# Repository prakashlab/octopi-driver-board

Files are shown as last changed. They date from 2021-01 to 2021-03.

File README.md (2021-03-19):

# octopi-driver-board

Driver electronics for the Octopi and Squid microscope families.

3D render of the driver electronics stack

This repository contains the design files for printed circuit boards (PCBs) for driving the sensors and actuators of the Octopi and Squid families of microscopes.

## Background

### Motivation

[Octopi](https://www.biorxiv.org/content/10.1101/684423v1), short for _Open configurable high-throughput imaging platform for infectious disease diagnosis_, is a low-cost and reconfigurable autonomous microscopy platform capable of automated slide scanning and correlated bright-field and fluorescence imaging. It has been developed for malaria microscopy, and its modular design also provides a framework for new disease-specific modules to be developed.

Photo of the Octopi microscope

[Squid](https://squid-imaging.org/), short for _Simplifying quantitative imaging platform development and deployment_, is a toolkit for implementing research microscopes with advanced imaging capabilities comparable to what's available in commercial solutions, but at a fraction of the cost and with much higher portability. Squid provides a full suite of hardware and software components for rapidly configuring high-performance microscopes tailored to users' applications with reduced cost, effort, and turnaround time. Besides increasing accessibility of research microscopes and available microscope hours to labs, it is also designed to simplify development and dissemination of new or otherwise advanced microscopy techniques.

CAD renders of three configurations of the Squid microscope

Because the modules of the Octopi and Squid microscopes contain various sensors and actuators which need to be electronically driven and integrated into a complete system, the Squid project also provides printed circuit boards for interfacing and controlling these modules. This repository contains the designs for printed circuit boards needed to drive these microscopes.

### Design Overview

Subsystems of the driver electronics are organized as discrete modules which are integrated into the overall system by being stacked. These modules are PCBs which are electrically connected through board-to-board connectors and mechanically connected through standoffs at their corners, reminiscent of the [PC/104](https://en.wikipedia.org/wiki/PC/104) family of standards for embedded computer form factors and communication buses. The stacking system is called the _Octopi Driver Stack_ (ODS), while the boards which are stacked are called _planes_. There are also boards which are not part of the stack but rather connect to planes; because these are peripheral to the system, they are called _peripheral boards_. Planes and peripheral boards may also have smaller circuit boards mounted onto them, which are called _daughter boards_.

Each board is given a two-part name code, consisting of a name code for the type of board followed by a name code for the specific design of the board. Each board is associated with a version of the Octopi Driver Stack (which provides information about compatibility between planes) and an independent version of the board itself (which provides information about functionality within planes and connector interfaces between the plane and daughter boards or peripheral boards). Version numbers follow the [Sematic Versioning 2.0.0](https://semver.org/) specification.

ODSv1.0.0 consists of planes measuring 150 mm x 150 mm which are all connected to each other by shared data and power bus lines for all GPIO provided by a microcontroller. Each corner of a plane has a mounting hole sized for an M3 standoff; these mounting holes are spaced 140 mm apart, with 5 mm between the center of each hole and its two nearest edges. Each corner of the plane is a rounded corner of radius 5 mm. The four edges of each plane are allocated to different functionalities:

- The front edge contains indicator LEDs, as well as connectors and circuity for the shared data and power bus lines which connect all planes together in a stack. In this project, these connectors and circuitry are collectively called the _backbone_ of ODSv1.0.0; at the level of hardware these elements are just a bus like in the PC/104 architecture, but our project uses the term "backbone" so that we can use the word "bus" only to describe standard buses (e.g. SPI, I2C) which the "backbone" is organized around. Each plane has two connectors for the backbone system, and they are at the same position but on opposite faces of the PCB. On the bottom face, a Hirose [FunctionMAX FX20-120S-0.5SV](https://www.hirose.com/product/p/CL0570-1105-6-00) receptacle is used. On the top face, a Hirose FunctionMax [FX20-120P-0.5SV15](https://www.hirose.com/product/p/CL0570-1005-1-00) header or [FX20-120P-0.5SV20](https://www.hirose.com/product/p/CL0570-1011-4-00) header is used, depending on the height of components on the top face of the board. These connectors are positioned so that their centers are 55 mm from the left edge of the plane and 35 mm from the front edge of the plane. The connectors are oriented so that their long edges are parallel with the front and rear edges of the plane, and so that pin 1 is farthest from the left-front corner of the plane.
- The left edge contains input and output power connectors.
- The right edge contains analog and digital signal connectors.
- The rear edge contains rarely-used or rarely-accessed connectors.

ODSv1.0.0 consists of a single central processing plane (board type name code `PP`, short for _Processing Plane_), which is stacked together with other planes consisting mainly of SPI devices, such as for:

- Motion control (board type name code `MP`, short for _Motion Plane_)
- Camera synchronization (board type name code `CP`, short for _Camera Plane_)
- Illumination control (board type name code `IP`, short for _Illumination Plane_)
- Thermal control (board type name code `TP`, short for _Thermal Plane_)
- Sensing (board type name code `SP`, short for _Sensing Plane_)
- Fluids control (board type name code `FP`, short for _Fluids Plane_)
- I/O prototyping breakout (board type name code `BP`, short for _Breakout Plane_)

The SPI devices on these planes are addressed through [a hierarchical chip-select multiplexing scheme](https://ethanj.li/posts/2021/01/unyielding-foundations#iteration-3-more-modularity-becomes-necessary) to enable composition of planes for customization, reconfiguration, and expansion of capabilities.

Every plane is separated by a distance of either 15 mm or 20 mm from the plane above it, depending on the height of components on the top face of the plane. All tall components should only be on the top face of the plane.

## Install

To set up your computer for using this repository, you will need to install [KiCad](https://kicad.org/) version 5.1.9; note that this repository relies on KiCad footprints which exist in 5.1.9 and not in earlier versions. You should have the default symbol, footprint, and 3-D model libraries provided by KiCad. References to custom symbols, footprints, and 3-D models will work out-of-the-box, as they are all provided in this repository and referenced in KiCad relative to the `${KIPRJMOD}` environment variable.

To prepare 3D models for components, you will need to download [FreeCAD 0.19](https://github.com/FreeCAD/FreeCAD/releases/tag/0.19_pre) and install the [KiCad StepUp workbench](https://github.com/easyw/kicadStepUpMod).

## Usage

This repository is structured so that every board has its own top-level directory with the following naming scheme:

- Templates: `ODSv<Octopi Driver Stack version>-<template type name code>-<specific design name code, if any>`
- Planes: `ODSv<Octopi Driver Stack version>-<board type name code>-<specific design name code>`
- Peripheral boards and daughter boards: `<board type name code>-<specific design name code>`

Each directory has a short README describing the contents of the directory. All boards are designed in KiCad. Only the most recent version of each board is included at the HEAD of the repository; older versions of boards are tagged on Git and archived in this repository's Github Releases. You can review the design files without KiCad, by viewing [this project on CADLab.io](https://cadlab.io/project/23992).

Templates are provided as starters to copy for creating new boards. For more information, refer to [ODSv1.0.0-BT/README.md](ODSv1.0.0-BT/README.md).

All footprints, documentation, CAD models, and KiCad libraries for components and daughter boards used with the ODSv1.0.0 boards are available in the `Parts` directory.

Unit tests for the ODSv1.0.0 boards are available in the `Tests` directory. These are Arduino sketches intended to be uploaded to the Teensy for basic verification of board functionality.

A KiCad project which mechanically integrates all planes in the ODSv1.0.0 stack for 3D rendering is in the `ODSv1.0.0` directory.

### Extending Functionality

This repository will provide planes and boards which implement a core set of functionalities. When you need to prototype new functionalities integrated into the driver stack, you should the [ODSv1.0.0-BP-Jmp](ODSv1.0.0-BP-Jmp) breakout plane, which is designed to enable prototyping. To start out, just connect the components you need with jumper wires to the various header pins on that plane; whenever possible, you should prefer using the SPI bus and the pins in the GPIO section. If you run out of available GPIO pins, if you need to assemble many copies of your prototype, or if you need more breakouts, then you should integrate your components as a new plane and, ideally, submit your plane to this repository. To do so:

1. Wherever possible, shift your use of GPIO pins on BP-Jmp to the plane's SPI I/O expanders for digital I/O, ADC, and DAC. The headers for those components are in the middle of the plane.
2. Create a new plane as a copy of the [ODSv1.0.0-BT](ODSv1.0.0-BT) starter template. For more information, refer to [ODSv1.0.0-BT/README.md](ODSv1.0.0-BT/README.md).
3. Add the standardized SPI I/O expanders, which are used in the BP-Jmp plane, to meet your GPIO needs; and add other SPI devices as needed. You will need to add the standardized pull-up resistor on the CS pin of each SPI device. For devices whose DOUT/DO/MISO/CIPO pins are not tri-state, you will need to add the standardized tri-state buffer between the pin and the CIPO line, which should be controlled by the same demultiplexed DCS line as the SPI device's CS pin; this tri-state buffer also needs a standardized bypass capacitor.
4. Add I2C devices if no alternative with an SPI interface is available. You will need to add the standardized bus switch between the SDA/SCL pins of each device and the SDA/SCL bus, and you should control the bus switch using one of the demultiplexed DCS lines; you will need to add the standardized pull-up resistor onto this line. This bus switch also needs a standardized bypass capacitor.

Where appropriate, you should delegate functions in your plane onto daughter boards. For example, if there is a particularly complex or expensive subsystem which you need to be able to swap out or test independently, or if you are reusing the same subsystem multiple times, you may want to make daughter board PCBs - each with one copy of the subsystem - which you can plug in to your new plane.

### Releases

Snapshots of boards for fabrication/assembly are tagged and associated with releases. Each release comes with the following attachments:

- The schematic diagram (`*-schematic.pdf`)
- A drawing of the footprints and silkscreens on the top face of the board (`*-silk-top.pdf`)
- A 2-D rendering of the top face of the board, including copper and silkscreens (`*-board-*-top.png`)
- Gerber and drill files for fabricating the board with PCBway (`*-gerb.zip`)
- A complete archive of all diagrams, drawings, renderings, and fabrication and assembly files for the board (`*-docs-rev*.zip`)

### Automated Exports

The assets attached with releases are automatically generated from a Github Actions workflow in this repository. This workflow is automatically run for commits in all pull requests and for any pushed commit.

The workflow can also be manually triggered from the [KiCad Exports](https://github.com/prakashlab/octopi-driver-board/actions?query=workflow%3A%22KiCad+Exports%22) page, with the following parameters:

- Branch: Use this to specify which branch to use for the workflow.
- Git ref: Use this to specify which commit of the design files to export. If you leave it blank, it will do an export from the most recent commit on the selected branch. If you give it a tag name or commit SHA hash, the workflow will export files from the corresponding commit.
- Boards: Use this to specify which boards to export. If you leave it blank, it will export all boards. If you want to export multiple boards, separate their names with spaces (e.g. `ODSv1.0.0-PP-T41 ODSv1.0.0-CP-5x`).
- Variants: Use this to specify which variants of each board to export. If you leave it blank, it will export only the default variant of all specified boards. You should only use this field if you have specified exactly one board to export; otherwise, leave it blank. If you want to export multiple variants, separate them with spaces (e.g. `Default Pufferfish`).

## Maintainers

Currently the maintainer of this repository is [Ethan Li](https://github.com/ethanjli).

## Contributing

The ODSv1.0.0 system is still at an early stage, and we do not have capacity to provide extensive support to people interested in contributing to the project. We have not yet set up public infrastructure for users to ask questions. We will look at pull requests but we do not yet have a process for accepting them. However, we are excited to build a community of contributors, so as this repository matures we will work to set up these processes and systems.

All contributions should be made through pull-requests. Before a pull request is merged, every author or co-author of the pull request must add a comment answering the following questions:

1. This project is licensed under Apache License v2.0 for any software, and Solderpad Hardware License v2.1 for any hardware - do you agree that your contributions to this project will be under these licenses, too? **Indicate response here** (the contributions will only be accepted if all co-authors agree)
2. Were any of these contributions also part of work you did for an employer or a client? If so, do you have their permission to release it? **Indicate responses to both questions here** (the contributions will only be accepted if the answer to the first question is "no", or when the answer to the second question is "yes").
3. Does this work include, or is it based on, any third-party work which you did not create? If so, what is it licensed under, and what modifications, if any, did you make to it? **Indicate response here** (before the contributions are accepted, use of those third-party works will need to be recorded, license compatibility will need to be checked, and license notices will need to be retained within the repository; we are happy to support you in getting these things in order)

## License

Copyright Prakash Lab and the Octopi project contributors.

SPDX-License-Identifier: Apache-2.0 WITH SHL-2.1

Except where otherwise indicated, all work in this repository is licensed under the [Solderpad Hardware License v2.1](LICENSE) (the “License”); you may not use files except in compliance with the License, or, at your option, the [Apache License version 2.0](LICENSE.Apache). You may obtain a copy of the License at https://solderpad.org/licenses/SHL-2.1/

Unless required by applicable law or agreed to in writing, any work distributed under the License is distributed on an “AS IS” BASIS, WITHOUT WARRANTIES OR CONDITIONS OF ANY KIND, either express or implied. See the License for the specific language governing permissions and limitations under the License.

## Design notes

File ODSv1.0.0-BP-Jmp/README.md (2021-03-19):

# Breakout Plane for Jumper Wires _(BP-Jmp)_

Male header breakout for the Octopi Driver Stack for prototyping directly with jumper wires

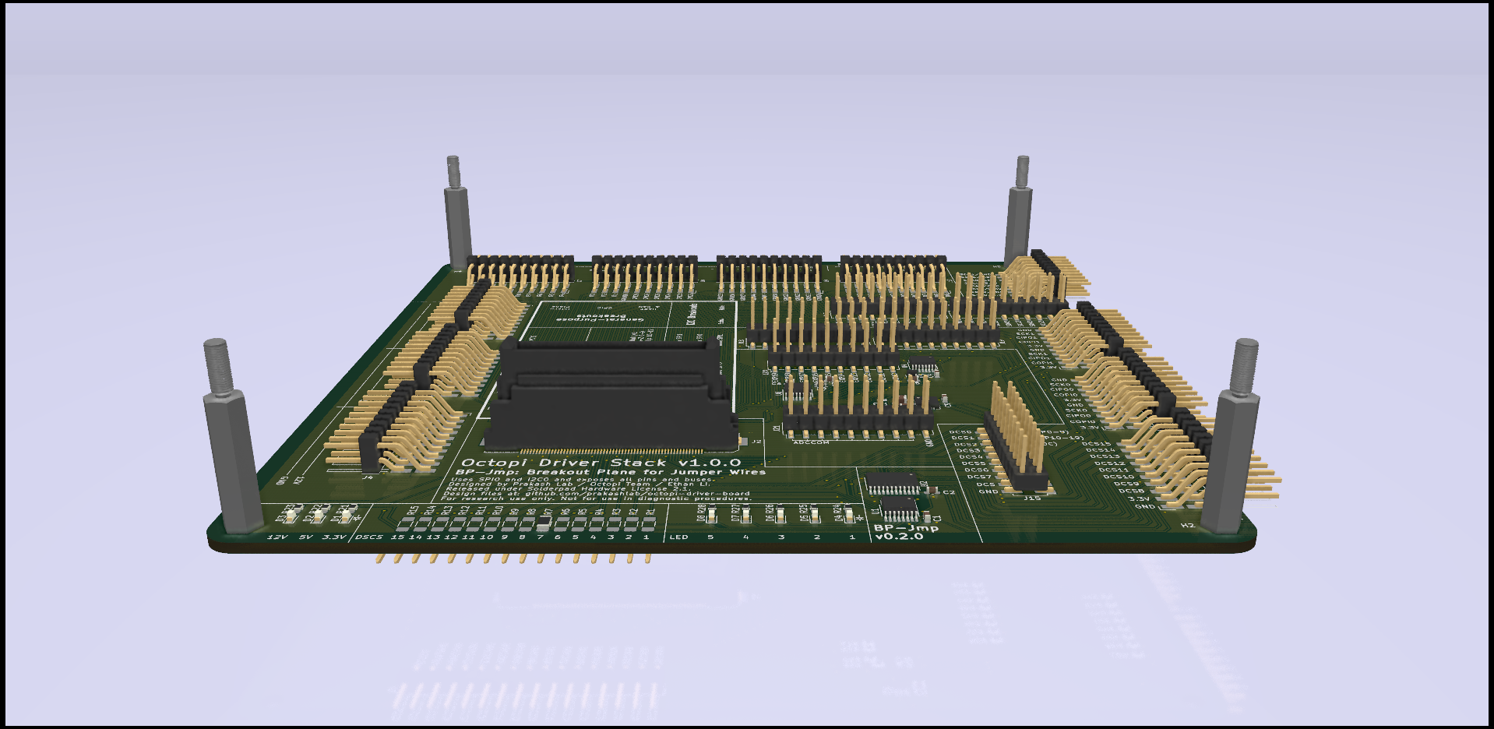
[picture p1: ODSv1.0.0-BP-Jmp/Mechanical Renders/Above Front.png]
Mechanical render of top face of the plane, from the front edge


This board template is part of the [octopi-driver-board project](https://github.com/prakashlab/octopi-driver-board).

This processing plane contains 0.1" pitch male headers directly exposing all lines of the driver stack's backbone. It also includes a digital I/O expander, a PWM driver, and an ADC for additional prototyping use; those peripherals are part of the driver stack's multiplexed SPI system.

## Background

The backbone uses a custom fine-pitch connector as well as a novel SPI chip-select multiplexing system. This plane exposes everything in the backbone for prototyping use, and includes a few on-board SPI devices which use the SPI chip-select multiplexing system.

This plane is designed to provide the following functionalities:

- Expose all of the driver stack's backbone lines, including power rails, GPIO pins, inter-plane lines, communication buses, and the SPI demultiplexed chip-select lines for prototyping with jumper wires. This is useful for testing new components and for probing the system with oscilloscopes and logic analyzers.
- Provide provide additional digital I/O, PWM, and ADC pins for prototyping use

This plane is not associated with any daughter boards.

This plane is not associated with any peripheral boards.

This plane has the following internal features:

- A 10-port digital I/O expander (MAX7317)
- A 10-port digital I/O expander whose I/O ports are connected to pull-up resistors to 3.3V (MAX7317)
- A 16-port PWM driver (not yet added, will be a PCA9685)
- A 8-port analog-to-digital converter (AD7689)

This plane has the following groups of external connectors, all in the form of 0.1" pitch male header:

- Plane edges: right-angle headers are used so that they can be physically accessed even if another plane is stacked on top of this plane. These headers collectively expose all of the backbone's signal and power lines. With one exception, all headers are two-row headers and are on the top face of the board. The exception is a one-row header on the bottom face of the board which exposes the DSCS lines of the SPI chip-select multiplexing system for probing.

This plane has the following backbone power interface:

- Power input: 3.3 V, 5 V, and 12 V from the backbone. To avoid power supply contention, the 3.3 V and 5 V pins on this board should not be connected to a power source. The 12 V pins on this board should not be connected to a power supply if the processing plane PP-T41 is already connected to a power supply.

This plane has the following backbone data interface:

- GPIO input/output: all GPIO pins from the backbone are exposed through external connectors for prototyping and probing use.
- Serial comunication: all UART/CAN serial communication lines from the backbone are exposed through external connectors through one port each. The fast and slow I2C communication buses from the backbone are exposed through five ports each. The alternate I2C/alternate UART serial communication bus is exposed through five ports. Both SPI communication buses are exposed through eight ports each. This board uses SPI0 for SPI chip-select multiplexing and for on-board devices.
- SPI chip-select multiplexing: this board reserves the DSCS7 line for use with SPI0; to avoid SPI bus contention, it should not be combined with other planes which reserve the DSCS7 line for use with SPI0. This board exposes DSCS1 - DSCS15 through an external connector with one pin each for probing. All demultiplexed DCS lines are exposed through external connectors with two pins each (one for connection to an SPI device, one for probing).

## Usage

This plane has the following mechanical stacking usage requirements:

- This plane should be placed at the top of the driver stack in order for the connections to the vertical male headers to be accessible. If only the right-angle headers at the board edge are needed, additional planes may be stacked on top of this one.
- The top face of the board requires a between-board separation of 20 mm from the plane above it, if another plane is stacked on top. This can be achieved with a [Keystone 24341](https://www.digikey.com/en/products/detail/keystone-electronics/24341/1532142) standoff on each of mounting holes H1-H4.

This plane has the following BOM variants:

- Default: A fully-populated PCB.
- NoExpansion: A PCB without components populated for I/O expansion (digital I/O expander, PWM driver, and ADC). This reduces the parts cost of the board by $25, because the ADC costs approx. $12.
- NoIC: A PCB without components populated for SPI device multiplexing or populated for I/O expansion (digital I/O expander, PWM driver, and ADC). This acts as a pure breakout for the backbone, without any extras. This only saves an additional approx. $8 beyond the NoExpansion variant, but it significantly reduces the number of parts to assemble, which may reduce assembly costs.

The following components can be manually swapped out in the BOM, though this is not officially supported:
- The AD7689 ADC can be replaced with a cheaper option such as the AD7682, AD7699, or the AD7949.

This plane allows the following post-assembly modifications:

- A 0 Ohm jumper resistor in the DSCS configuration jumper array can be moved from one place to another in order to change which DSCS line this plane reserves for SPI chip-select multiplexing.

This plane has the following safety notices:

- Both power and data pins on external connectors are exposed through male headers. Be careful not to short any of the pins together, especially the power pins.

### Teensy Pin Mappings

While almost all GPIO header pins of the Teensy 4.1 on the processing plane are exposed in this plane, not all of them are labeled according to the Teensy pin numbers. Here is a table of correspondences between Teensy pins and header pins on this plane:

|Teensy Pin|BP-Jmp Pin|BP-Jmp Section |GPIO Functions |
|---|---|---|---|
|GND |GND |Various edges and sections | |
|3.3V |3.3V |Various edges and sections | |
|Vin |5V |Left Edge: 5V | |
|0 |CRX2 |Rear Edge: UART & CAN |CAN2, SER1, PWM |
|1 |CTX2 |Rear Edge: UART & CAN |CAN2, SER1, PWM |
|2 |2 |Rear Edge: GPIO |PWM |
|3 |3 |Rear Edge: GPIO |PWM |
|4 |4 |Rear Edge: GPIO |PWM |
|5 |5 |Rear Edge: GPIO |PWM |
|6 |6 |Rear Edge: GPIO |PWM |
|7 |RX2 |Rear Edge: UART TX/RX |SER2, PWM |
|8 |TX2 |Rear Edge: UART TX/RX |SER2, PWM |
|9 |9 |Rear Edge: GPIO |PWM |
|10 |10 |Rear Edge: GPIO |PWM |
|11 |COPI0 |Right Edge: Main SPI0 |SPI0 |
|12 |CIPO0 |Right Edge: Main SPI0 |SPI0 |
|13 |SCK0 |Right Edge: Main SPI0 |SPI0 |
|14/A0 |TX3 |Rear Edge: UART & CAN |SER3, PWM, ADC |
|15/A1 |RX3 |Rear Edge: UART & CAN |SER3, PWM, ADC |
|16/A2 |SCL1 |Right Edge: Main I2C |I2C1, SER4, ADC |
|17/A3 |SDA1 |Right Edge: Main I2C |I2C1, SER4, ADC |
|18 |SDA0 |Right Edge: Main I2C |I2C0 |
|19 |SCL0 |Right Edge: Main I2C |I2C0 |
|20/A6 |20 |Rear Edge: GPIO |SER5, ADC |
|21/A7 |21 |Rear Edge: GPIO |SER5, ADC |
|22/A8 |22 |Rear Edge: GPIO |CAN1, PWM, ADC |
|23/A9 |23 |Rear Edge: GPIO |CAN1, PWM, ADC |
|24/A10 |SCL2 |Right Edge: Main I2C |I2C2, SER6, PWM, ADC|
|25/A11 |SDA2 |Right Edge: Main I2C |I2C2, SER6, PWM, ADC|
|26/A12 |COPI1 |Right Edge: Main SPI1 |SPI1 |
|27/A13 |SCK1 |Right Edge: Main SPI1 |SPI1 |
|28 |TX7 |Rear Edge: UART & CAN |SER7, PWM |
|29 |RX7 |Rear Edge: UART & CAN |SER7, PWM |
|30 |N/A |N/A | |
|31 |N/A |N/A | |
|32 |DCS |Front Edge: Extra Device CS| |
|33 |33 |Rear Edge: GPIO |PWM |
|34 |RX8 |Rear Edge: UART TX/RX |SER8 |
|35 |TX8 |Rear Edge: UART TX/RX |SER8 |
|36 |36 |Rear Edge: GPIO |PWM |
|37 |37 |Rear Edge: GPIO |PWM |
|38/A14 |38 |Rear Edge: GPIO |ADC |
|39 |CIPO1 |Right Edge: Main SPI1 |SPI1 |
|40/A16 |40 |Rear Edge: GPIO |ADC |
|41/A17 |41 |Rear Edge: GPIO |ADC |

Note that Teensy pins 30 and 31 are not exposed by PP-T41 over the backbone, so they are not exposed by this plane. They are exclusively used by PP-T41, and if you need to probe them, you can solder a header to a location provided on the board for this purpose.

You should not attempt to use the SPI0, SPI1, or I2C0 pins as GPIOs. If you want to use any of the other I2C or UART/CAN pins as GPIOs for prototyping, you can do so as long as your other planes are not already using them. For example, PP-T41 uses pins 22 and 23 if you connect an HB-* board to it. In the standard allocation, there are 15 pins reserved for GPIO (excluding pins 22 and 23), as well as up to 14 pins designated for UART/CAN/I2C which may be used instead for GPIO-based prototyping if they are available.

As a special example, the I2C1 and I2C2 signal lines are each connected to 5 header pins, so if I2C1 or I2C2 isn't already being used and you need to plug multiple wires directly onto the same signal line, you can use SDA1, SCL1, SDA2, and/or SCL2. Since I2C1 can also serve as SER4 and I2C2 can also serve as SER6, you can also directly use jumper wires to connect up to 5 UART serial devices together on the same pair of signal lines, if they are designed for such use.

### I/O Peripherals

#### Digital Input/Output Expanders

This plane exposes 20 digital I/O pins connected to two [MAX7317](../Parts/ICs/SPI%20Peripherals/MAX7317/Datasheet.pdf) I/O expanders. The first MAX7317 is used for pins EXPIO0-EXPIO9, while the second is used for pins EXPIO10-19. Pins EXPIO0-EXPIO9 can be used either as high-impedance input pins or as open-drain output pins (i.e. the pin can be set to either floating or 0V); if you need output pins to drive devices such as LEDs which draw current, you should use these pins. Pins EXPIO10-EXPIO19 are connected to 3.3 V by 2 kOhm pullup resistors, so they can be used as either pullup input pins or as push-pull output pins (i.e. the pin can be set to either 3.3V or 0V); if you need output pins for 3.3V logic signals with no current draw, you should use these pins.

#### Analog-to-Digital Converter

This pin exposes 8 analog input pins connected to an [AD7689BCPZ](../Parts/ICs/SPI%20Peripherals/AD768x/Datasheet.pdf) ADC. This ADC can be configured through its SPI interface to use either the internal voltage reference, an external reference on the REFIN pin with the internal buffer outputting to the REF pin, or an external reference on the REF pin. It can also be configured through its SPI interface to read inputs referenced to either GND or ADCCOM as a common reference point. If you are referencing inputs to GND, you can connect one of the ADCCOM pins to the GND pin, so that you will have 8 GND pins to accompany the 8 analog input pins.

#### Pulse-Width Modulation Driver

TBD

## Maintainers

Currently the maintainer of this template is [Ethan Li](https://github.com/ethanjli).

## License

Copyright Prakash Lab and the Octopi project contributors.

SPDX-License-Identifier: Apache-2.0 WITH SHL-2.1

All work in this directory is licensed under the [Solderpad Hardware License v2.1](/LICENSE) (the “License”); you may not use files except in compliance with the License, or, at your option, the [Apache License version 2.0](/LICENSE.Apache). You may obtain a copy of the License at https://solderpad.org/licenses/SHL-2.1/

Unless required by applicable law or agreed to in writing, any work distributed under the License is distributed on an “AS IS” BASIS, WITHOUT WARRANTIES OR CONDITIONS OF ANY KIND, either express or implied. See the License for the specific language governing permissions and limitations under the License.

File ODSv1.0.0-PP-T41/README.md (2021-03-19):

# Processing Plane for Teensy 4.1 _(PP-T41)_

Central processing, control, and computation for the Octopi Driver Stack

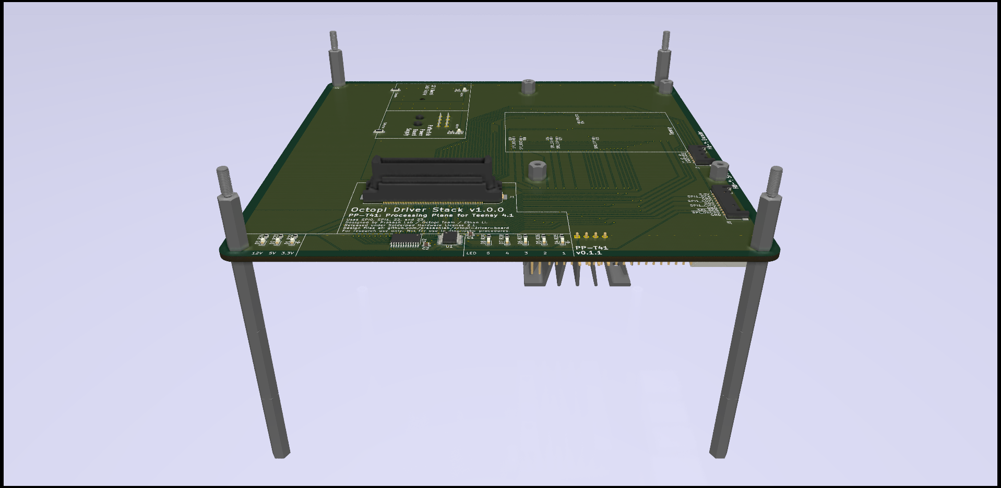
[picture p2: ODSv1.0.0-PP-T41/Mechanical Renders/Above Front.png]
Mechanical render of top face of the plane, from the front edge


This plane is part of the [octopi-driver-board project](https://github.com/prakashlab/octopi-driver-board).

This processing plane contains a [Teensy 4.1](https://www.pjrc.com/store/teensy41.html) microcontroller board and performs central control of all other devices in the driver stack. It also provides mounting holes for an [NVIDIA Jetson Nano Developer Kit](https://developer.nvidia.com/EMBEDDED/jetson-nano-developer-kit) which integrates the microcontroller with image acquisition and graphical user interfacing functionality. Each stack should have exactly one of these planes.

## Background

The Teensy 4.1, based on NXP Semiconductor's [i.MX RT1060](https://www.nxp.com/products/processors-and-microcontrollers/arm-microcontrollers/i-mx-rt-crossover-mcus/i-mx-rt1060-crossover-mcu-with-arm-cortex-m7-core:i.MX-RT106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) [Crossover Processor](https://www.nxp.com/docs/en/white-paper/I.MXRT1050WP.pdf), is (along with the Teensy 4.0) the fastest microcontroller development board in existence. The i.MX RT1060 has an ARM Cortex-M7 core with a CPU clock speed of up to 600 MHz, 1 MB of RAM, and a dedicated floating-point math unit. This plane electrically integrates the Teensy 4.1 with the driver stack's backbone system.

This plane is designed to provide the following functionalities:

- Low-level and real-time control of components driven by the stack, with the Teensy 4.1
- (Optionally) High-level computation, with the NVIDIA Jetson Nano
- Human-machine interfacing, delegated to a peripheral board
- Mechanical base for all other planes in the driver stack
- Module switching for the backbone's hierarchical SPI chip-select multiplexing system

This plane is associated with the following daughter boards:

- Teensy 4.1 [with male headers](https://www.pjrc.com/store/teensy41_pins.html), on the bottom face of the plane at the right edge of the board.
- NVIDIA Jetson Nano Developer Kit on the bottom face of the plane at the right edge of the board, but only through standoffs for mechanical mounting. The Teensy 4.1 is intended to be connected to the Jetson Nano through a short USB cable for power and data.

This plane is associated with the following peripheral boards:

- HB-Sm: HMI Board with Small Interface

This plane has the following internal features:

- 0 Ohm resistor pads to choose whether 12 V power is taken from the 12 V DC barrel jack or from a Pufferfish Power Board
- A 220 uF bulk capacitor on the 12 V power supply input

This plane has the following external connectors:

- [Molex Ultra-Fit 2x4 Header](https://www.molex.com/molex/products/part-detail/pcb_headers/1723161108) for receiving power from a Pufferfish Power Board, at the left edge of the board.
- [12 V DC Barrel Jack](https://www.digikey.com/en/products/detail/cui-devices/PJ-036AH-SMT-TR/1530971) for external power supply from a wall wart, at the left edge of the board. The dimensions of this barrel jack are the same as for the Arduino Uno.
- A [10-pin Molex Pico-Lock Header](https://www.digikey.com/en/products/detail/molex/5040501091/4357650) and a [6-pin Molex Pico-Lock Header](https://www.digikey.com/en/products/detail/molex/5040500691/4357148) at the right edge of the board to interface with HB-Sm.

This plane has the following backbone power interface:

- Power output: 3.3 V and 5 V from the Teensy board, and 12 V from the external supply. To avoid power supply contention, no other plane should output power onto the corresponding pins in the backbone.

This plane has the following backbone data interface:

- GPIO input/output: almost all GPIO pins from the Teensy are exposed for other planes to interface with.
- GPIO output: Pins 22 and 23 of the Teensy are exposed over the backbone but are also connected to outputs from HB-Sm; they should not be used by other planes.
- Serial comunication: Most GPIO pins which correspond to I2C and CAN buses and or to UART Serial connections are reserved for those purposes and laid out in a special section of the backbone for other planes to interface with. Both SPI buses from the Teensy are also exposed over the backbone for other planes to interface with. SPI1 is used for peripheral boards and devices such as HB-Sm, while SPI0 is to intended for use by planes. In particular, this plane uses Teensy pins 11, 12, and 13 for COPI0, CIPO0, and SCK0, respectively, and Teensy pins 26, 39, and 27 for COPI1, CIPO1, and SCK1, respectively.
- SPI chip-select multiplexing: this board reserves the DSCS0 line for use with SPI0 and SPI1 for on-board devices and HB-Sm; the DSCS0 line is not exposed over the backbone. This board exposes DSCS1 - DSCS15 for other planes to use.

## Usage

This plane has the following mechanical stacking usage requirements:

- This plane must be placed at the bottom of the driver stack.
- The top face of the board requires a between-board separation of 15 mm from the plane above it. This can be achieved with a [Keystone 24339](https://www.digikey.com/en/products/detail/keystone-electronics/24339/1532140) standoff on each of mounting holes H1-H4.
- The bottom face of the board requires a separation of 75 mm from the surface on which this plane is placed, to allow sufficient clearance for the Jetson Nano Developer Kit and a cooling fan which may be placed on its heatsink. This can be achieved with three [Keystone 24342](https://www.digikey.com/en/products/detail/keystone-electronics/24342/1532143) standoffs, screwed together, under each of mounting holes H1-H4.

This plane has the following BOM variants:

- Default: A fully-populated PCB, configured to take 12 V power supply input from the barrel jack and not from the Pufferfish Power Board.
- Pufferfish: A fully-populated PCB, configured to take 12 V power supply input from the Pufferfish Power Board and not from the barrel jack.
- NoPufferfish: A PCB which can only take 12 V power supply input from the barrel jack and omits components related to the Pufferfish Power Board.

This board has the following power supply connection instructions:

- Regardless of BOM variant, if an active power supply is plugged into its corresponding jack, an LED should light up next to the jack to indicate that the jack is energized.
- The BOM variant determines whether an energized jack is used to provide 12 V power to the stack. For example, in the Pufferfish variant, plugging in a 12 V DC adapter to the barrel jack will cause the LED next to the barrel jack to light up but will not provide 12 V supply to the stack; and the 12 V power indicator in the backbone section of the plane will not light up.

This plane allows the following post-assembly modifications:

- A 4-pin 0.1" pitch through-hole header can be soldered to the bottom of the plane at the front edge to expose jumper wire test points for probing the DSCS0, DSCS, MSCS, and GND lines. It is recommended to use a right-angle header with 0.23" contact length, such as [PRPC004SBAN-M71RC](https://www.digikey.com/en/products/detail/sullins-connector-solutions/PRPC004SBAN-M71RC/2775330).
- A 0 Ohm jumper resistor can be moved from one place to another in order to convert this between the Default and Pufferfish variants. This jumper resistor determines which power supply input (barrel jack or Pufferfish Power Board) can be used to supply 12 V to the plane. Note that this does not work with the NoPufferfish variant, which lacks the connector for the Pufferfish Power Board.
- A 0 Ohm jumper resistor can be added to the unpopulated location for a given variant in order to allow the operator to choose whether to power the plane from the barrel jack or the Pufferfish Power Board simply by plugging in **one** of the two power sources, rather than by moving the jumper. Note that this does not work with the NoPufferfish variant, which lacks the connector for the Pufferfish Power Board.

This plane has the following safety notices:

- If jumper resistors are added for both the barrel jack and the Pufferfish Power Board during post-assembly rework, there is **no protection** for connecting both the Pufferfish Power Board and a DC power supply to the plane at the same time. This is dangerous and should not be attempted. To reduce the risk of harm resulting from such an operator error, this plane does not provide a BOM variant with jumper resistors in both locations.

## Maintainers

Currently the maintainer of this board is [Ethan Li](https://github.com/ethanjli).

## License

Copyright Prakash Lab and the Octopi project contributors.

SPDX-License-Identifier: Apache-2.0 WITH SHL-2.1

All work in this directory is licensed under the [Solderpad Hardware License v2.1](/LICENSE) (the “License”); you may not use files except in compliance with the License, or, at your option, the [Apache License version 2.0](/LICENSE.Apache). You may obtain a copy of the License at https://solderpad.org/licenses/SHL-2.1/

Unless required by applicable law or agreed to in writing, any work distributed under the License is distributed on an “AS IS” BASIS, WITHOUT WARRANTIES OR CONDITIONS OF ANY KIND, either express or implied. See the License for the specific language governing permissions and limitations under the License.

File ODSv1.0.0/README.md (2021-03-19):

# Octopi Driver Stack

Mechanical integration of all boards in the Octopi Driver Stack

Mechanical render of the stack

This meta-board is part of the [octopi-driver-board project](https://github.com/prakashlab/octopi-driver-board).

This KiCad project is a meta-board which simply integrates the 3D models of all planes in the Octopi Driver Stack, for use in 3D export and rendering. See the [octopi-driver-board project README](../README.md) for more details. From top to bottom, this stack consists of the following boards:

- [ODSv1.0.0-BP-Jmp](../ODSv1.0.0-BP-Jmp)
- [ODSv1.0.0-PP-T41](../ODSv1.0.0-PP-T41)

A Blender project is also provided to render the entire stack from multiple viewpoints, with raytracing through Blender Cycles.

## Usage

### Rendering

For each of the boards listed above, open its KICAD_PCB file in KiCad and export it as a WRL file (VRML/X3D format) into this directory (**not the directory of the board**)) with the following settings:

- Units: 0.1 in
- Grid reference X, Y: 35 mm, 205 mm (this is the location of the center of mounting hole H1)

Then open ODSv1.0.0.kicad_pcb and export it as a WRL file into this directory with the following settings:

- Units: 1 m
- Grid reference X, Y: 105 mm, 135 mm (this is the location of the center of each plane)

Then import the resulting WRL file into a new project in [Blender 2.79b](https://www.blender.org/download/releases/2-79/) with X Forward and Z Up as the import settings, and export it as a Collada DAE file with the default settings after deleting the default cube, camera, and light from the scene; note that you will need to use this older version because the WRL file import is broken for color & material imports in later versions. Then import the resulting DAE file into the ODSv1.0.0.blend file using [the latest version of Blender](https://www.blender.org/download/) with [Auto-Run Python Scripts](https://docs.blender.org/manual/en/latest/editors/preferences/save_load.html#auto-run-python-scripts) allowed, and select "Render/Render Animation" from the menu to render the driver stack from the predefined camera angles. Raytracing will take a long time, but once it completes the images will be saved into the [Mechanical Renders](Mechanical%20Renders) directory.

### Modifying

To add a new plane to the stack, you will need to export it as a WRL file as described above, open ODSv1.0.0.kicad_pcb, and add the WRL file as a new 3D model to the H1 footprint. You will need to adjust the Z offset of this new 3D model. For a plane which needs to be 15 mm above the previous plane, its Z offset should be 16.6 mm greater than the Z offset of the previous plane (i.e. the PCB itself is 1.6 mm thick). For each plane which is 20 mm above the previous plane, its Z offset should be 21.6 mm greater than the Z offset of the previous plane. If you first export the ODSv1.0.0.kicad_pcb as a WRL file before trying to open any in-Kicad 3D renderers (e.g. the 3D models tab of the H1 footprint or the 3D viewer), the 3D renderers will load more quickly.

You will also need to move the cameras in the Blender project as you add more planes to the stack, and for camera angles which have depth of field focusing on selected objects you will need to re-select those objects.

## Maintainers

Currently the maintainer of this meta-board is [Ethan Li](https://github.com/ethanjli).

## License

Copyright Prakash Lab and the Octopi project contributors.

SPDX-License-Identifier: Apache-2.0 WITH SHL-2.1

All work in this directory is licensed under the [Solderpad Hardware License v2.1](/LICENSE) (the “License”); you may not use files except in compliance with the License, or, at your option, the [Apache License version 2.0](/LICENSE.Apache). You may obtain a copy of the License at https://solderpad.org/licenses/SHL-2.1/

Unless required by applicable law or agreed to in writing, any work distributed under the License is distributed on an “AS IS” BASIS, WITHOUT WARRANTIES OR CONDITIONS OF ANY KIND, either express or implied. See the License for the specific language governing permissions and limitations under the License.

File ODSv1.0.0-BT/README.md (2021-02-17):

# Backbone Template _(BT)_

Backbone Template for creating new planes in the Octopi Driver Stack

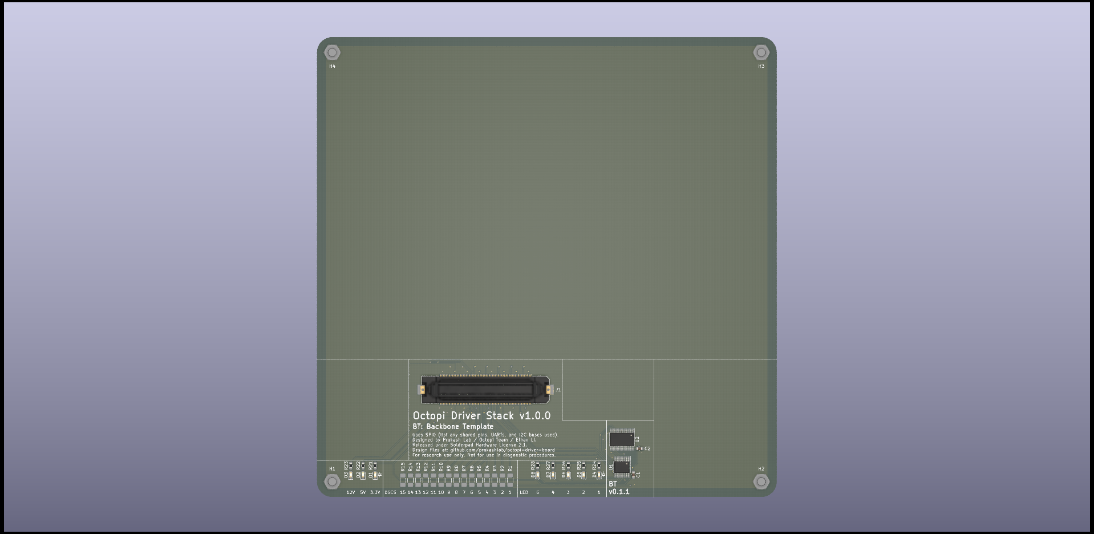
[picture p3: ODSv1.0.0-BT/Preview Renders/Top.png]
Preview render of top face of the plane


This board template is part of the [octopi-driver-board project](https://github.com/prakashlab/octopi-driver-board).

The Backbone template contains a customizable schematic and PCB layout of the subsystems repeated on every plane (except the processing plane) for connector stacking and hierarchical SPI chip-select multiplexing.

## Usage

This template is provided as a starter KiCad project to copy for creating new planes.  To create a new plane from this template:

1. Make a copy of this directory, with the appropriate name code for the name of your new directory (for example, `ODSv1.0.0-CP-5x` for a Camera Plane for 5 Cameras). Then rename the `ODSv1.0.0-BT.pro`, `ODSv1.0.0-BT.sch`, and `ODSv1.0.0-BT-cache.lib` `ODSv1.0.0-BT.kicad_pcb` files the same way (for example, `ODSv1.0.0-CP-5x.pro`, `ODSv1.0.0-CP-5x.sch`, `ODSv1.0.0-CP-5x.kicad_pcb`, and `ODSv1.0.0-CP-5x-cache.lib`).
2. Open the project in KiCad. In the page settings for the schematic and layout files, customize/update the title block parameters for your new plane. For example, the `Revision` field should be used to capture the specific version of your board.
3. Follow the customization instructions listed in the upper right corners of the various sheets of the schematic to customize the schematic according to your needs. For example, you will need to remove DNP from the Config field of the symbol fields for one of the resistors in the SPI DSCS Selector section of the Backbone sheet. Afterwards, you can delete the instructions from the upper right corners of the sheets.
4. Customize the silkscreen labels in the layout file, including the type codes, the full title, the designer credits, and the description of shared pins, UARTs, and buses used by the plane
5. If you have multiple BOM variants, edit the `variants.yml` file following the format described in the [KiBot assembly variants guide](https://inti-cmnb.github.io/kibot_variants_arduprog/) to define the variants, and also set values in the Config column of the schematic's symbol fields as described in that guide to define the relationships between components and variants. For each variant you define in `variants.yml`, you should use CamelCase for the name of the variant which you'd put in the Config column as the value of the `variant` property and the `name` property, while you should use prefixed it by a hyphen (`-`) as the value of the `file_id` property.
6. If you have tall components (e.g. daughter boards or big connectors) on the top face of the plane such that you need a clearance of 20 mm above the face rather than a clearance of 15 mm above the face, open the PCB layout file and change footprint J1's associated 3D model from `${KIPRJMOD}/../Parts/Connectors/FunctionMAX FX20/FX20-120P-0.5SV15.wrl` to `${KIPRJMOD}/../Parts/Connectors/FunctionMAX FX20/FX20-120P-0.5SV20.wrl`; and for mounting holes H1, H2, H3, and H4, change their associated 3D model from `${KIPRJMOD}/../Parts/Fasteners/Keystone Standoffs/24339.wrl` to `${KIPRJMOD}/../Parts/Fasteners/Keystone Standoffs/24341.wrl`. You'll also need to open the schematic's symbol fields to change the MPN, Digikey ID, and Ordering URL for J1 from `FX20-120P-0.5SV15` to `FX20-120P-0.5SV20`, `H12043-ND` to `H12042-ND`, and `https://www.digikey.com/en/products/detail/hirose-electric-co-ltd/FX20-120P-0-5SV15/3461671` to `https://www.digikey.com/en/products/detail/hirose-electric-co-ltd/FX20-120P-0-5SV20/3461672`, respectively.
7. For the default 0 Ohm resistor jumper to be populated into the Backbone section's DSCS configuration jumper array, add `${KISYS3DMOD}/Resistor_SMD.3dshapes/R_1206_3216Metric.wrl` as its associated 3D model.
8. Modify this README to describe the board; you can use [the README.md for ODSv1.0.0-BP-Jmp](/ODSv1.0.0-BP-Jmp/README.md) as an example for reference of what content to include and how to structure it.

You should avoid updating all footprints from the library, as this will wipe associated customization of 3D models for components; instead, only update footprints from library for the specific components you need to update.

## Maintainers

Currently the maintainer of this template is [Ethan Li](https://github.com/ethanjli).

## License

Copyright Prakash Lab and the Octopi project contributors.

SPDX-License-Identifier: Apache-2.0 WITH SHL-2.1

All work in this directory is licensed under the [Solderpad Hardware License v2.1](/LICENSE) (the “License”); you may not use files except in compliance with the License, or, at your option, the [Apache License version 2.0](/LICENSE.Apache). You may obtain a copy of the License at https://solderpad.org/licenses/SHL-2.1/

Unless required by applicable law or agreed to in writing, any work distributed under the License is distributed on an “AS IS” BASIS, WITHOUT WARRANTIES OR CONDITIONS OF ANY KIND, either express or implied. See the License for the specific language governing permissions and limitations under the License.

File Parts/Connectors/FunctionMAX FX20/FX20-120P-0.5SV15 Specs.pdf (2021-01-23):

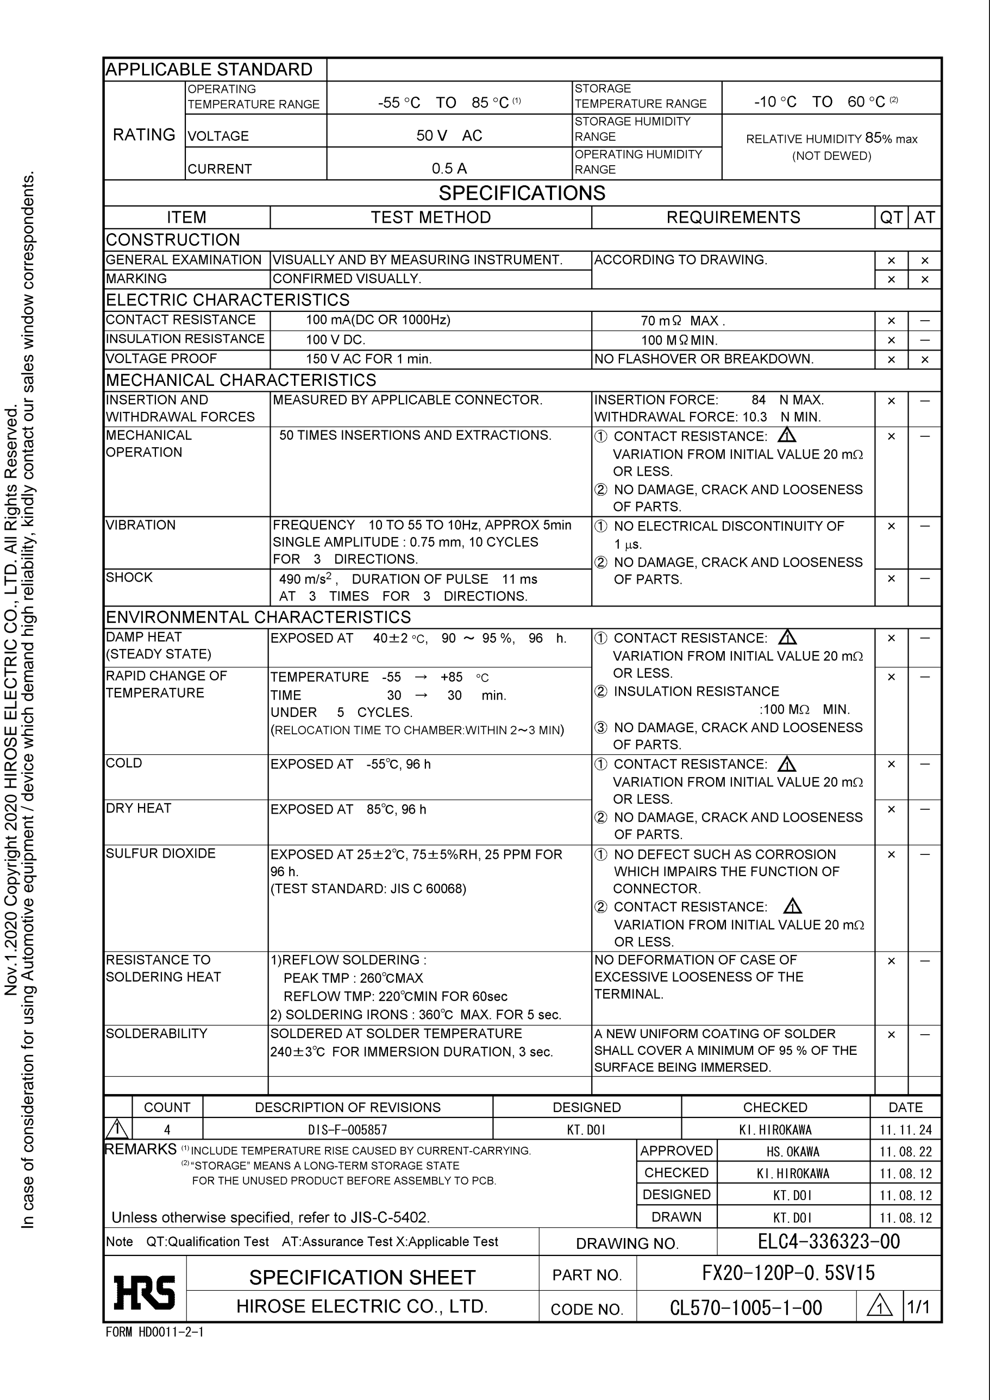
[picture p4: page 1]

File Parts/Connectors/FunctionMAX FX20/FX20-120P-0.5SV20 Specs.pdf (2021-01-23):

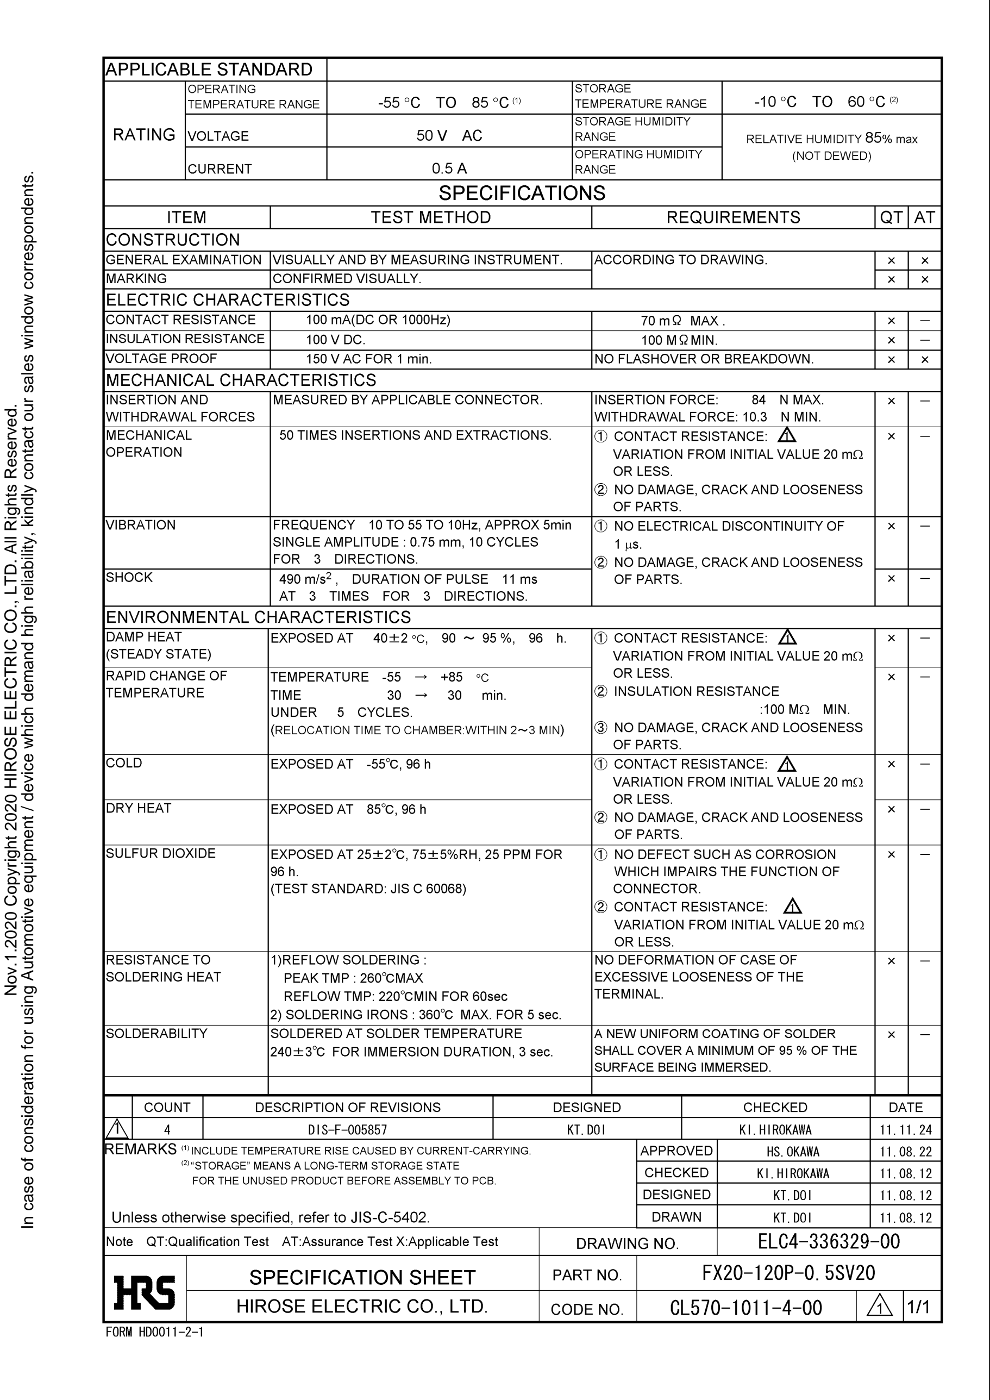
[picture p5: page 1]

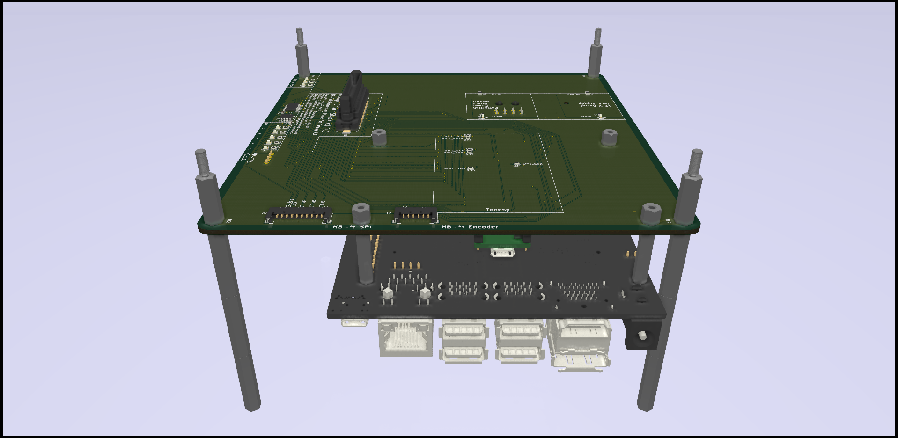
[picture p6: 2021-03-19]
ODSv1.0.0-PP-T41/Mechanical Renders/Above Right.png

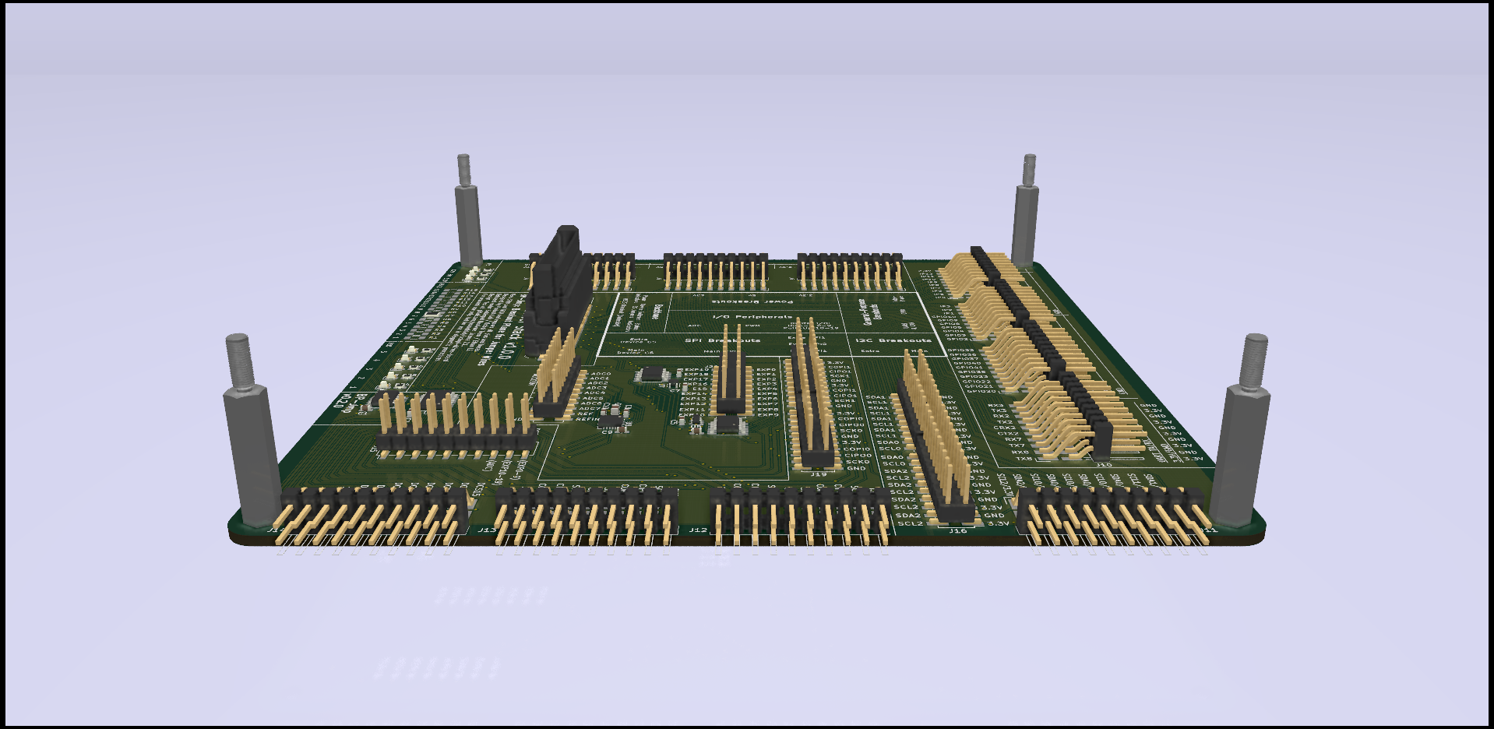
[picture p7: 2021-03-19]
ODSv1.0.0-BP-Jmp/Mechanical Renders/Above Right.png

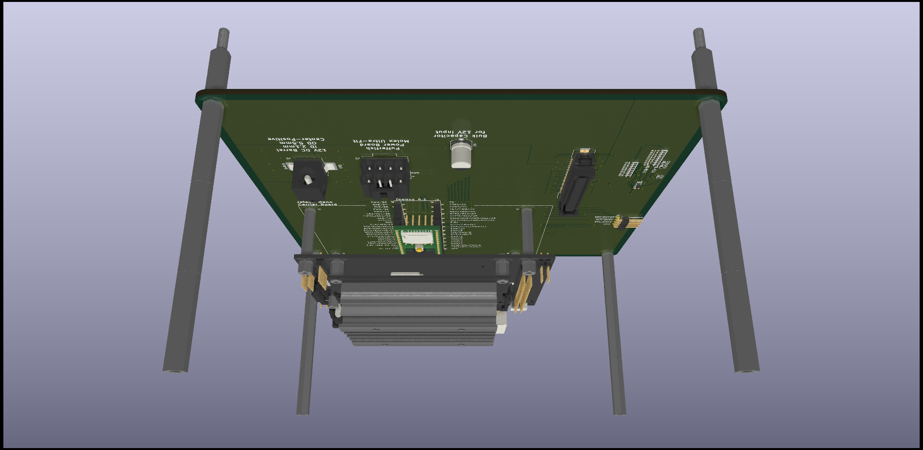
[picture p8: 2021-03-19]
ODSv1.0.0-PP-T41/Mechanical Renders/Below Left.png

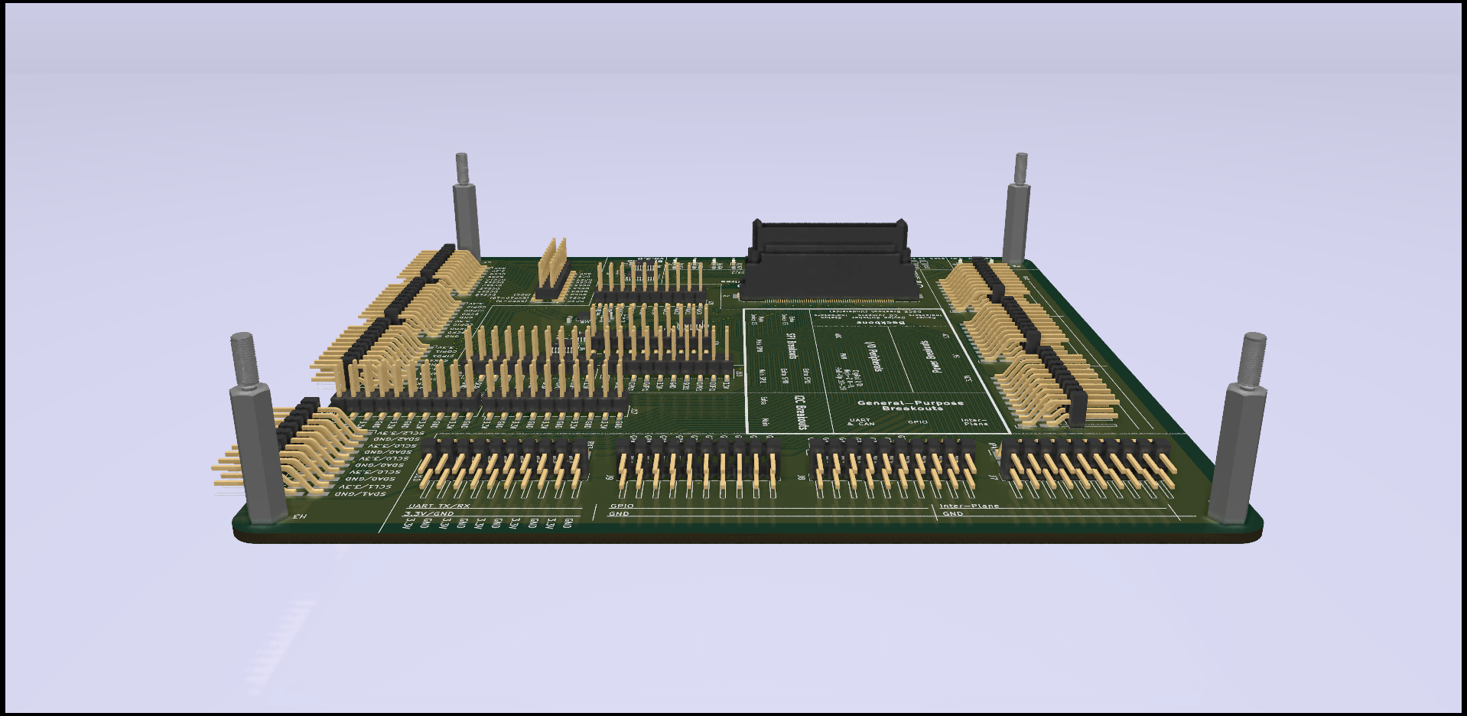
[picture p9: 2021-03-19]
ODSv1.0.0-BP-Jmp/Mechanical Renders/Above Rear.png

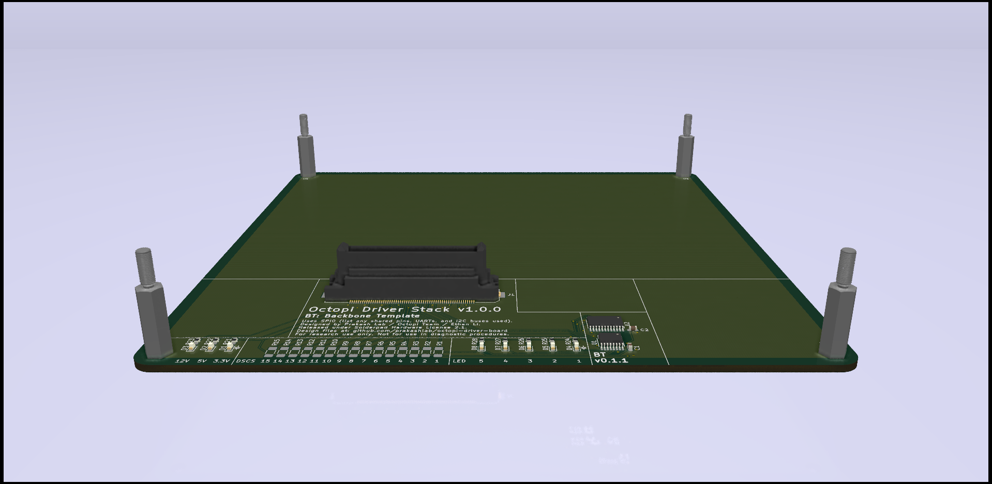
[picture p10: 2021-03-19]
ODSv1.0.0-BT/Mechanical Renders/Above Front.png

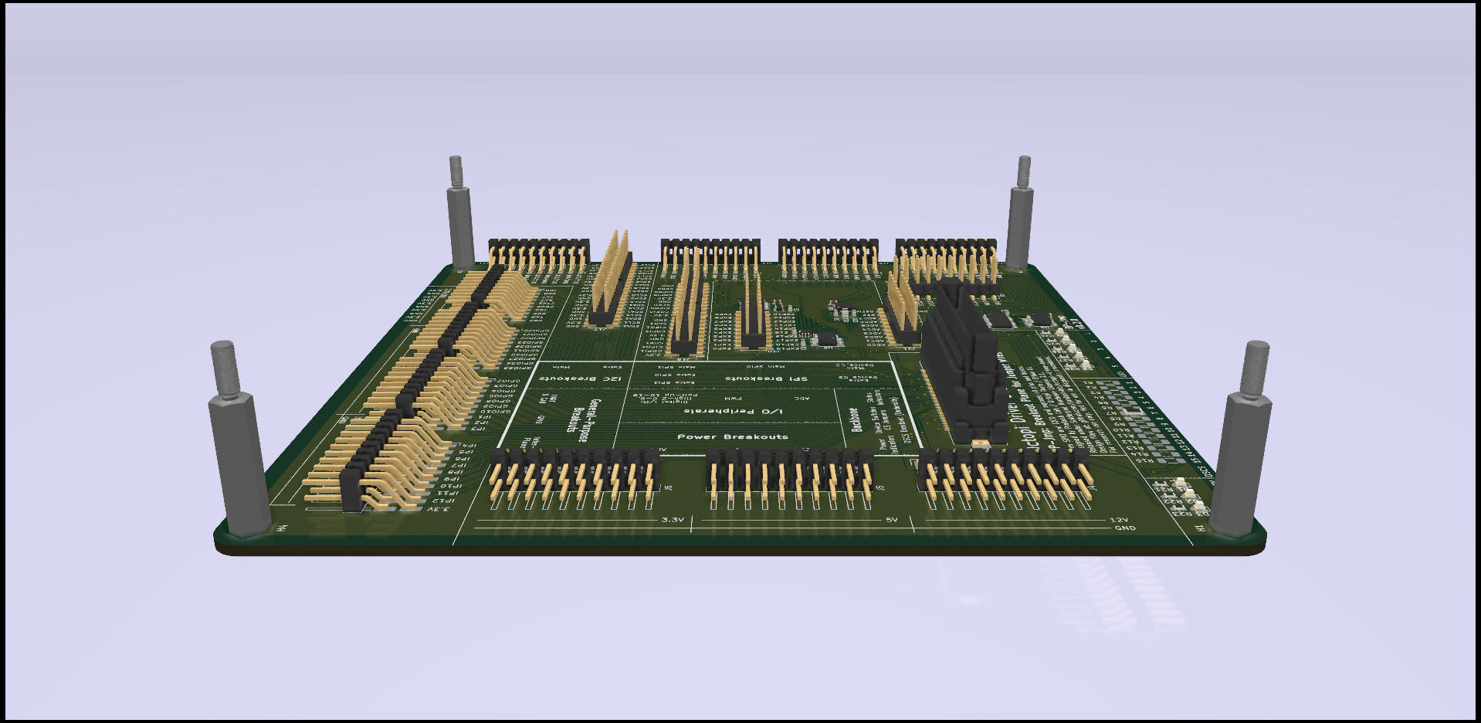
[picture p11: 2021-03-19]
ODSv1.0.0-BP-Jmp/Mechanical Renders/Above Left.png

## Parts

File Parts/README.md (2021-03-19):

# Parts

Documentation, specifications, symbols, footprints, and 3-D models for components used in the Octopi Driver Stack

## License

License information for files in subdirectories of the current directory can be found in `README.md` files within those subdirectories. License information for files in the current directory are included below.

## Octopi.dcm and Octopi.lib

KiCad symbols for one-off components used in the Octopi Driver Stack

### License

The symbol for `74HC4067PW` was created by Ethan Li as a modification of the `CD74HC4067` symbol in the `74xx` KiCad library. The specific modications made were:

- The center of the symbol was moved to be its actual geometric center
- The package and component name labels were changed to match what is used for the 74HC4067PW
- The I0 ... I15 pin labels were changed to Y0 ... Y15 to match the names used in the datasheet for the 74HC4067PW

The symbol for `MAX7317` was created by Ethan Li as a modification of the `MCP23S17_SO` symbol in the `Interface_Expansion` KiCad library. The specific modifications made were:

- All pins were changed, reassigned, and moved to match what is used for the MAX7317
- The package and component name labels were changed to match what is used for the MAX7317

The symbol for `DACx0508` was created by Ethan Li as a modification of the `DAC5578xPW` symbol in the `Analog_DAC` KiCad library. The specific modifications made were:

- All pins were changed, reassigned, and moved to match what is used for the DACx0508
- The package and component name labels were changed to match what is used for the DACx0508

The symbol for `AD7689xCP` was created by Ethan Li as a modification of the `AD7689xCP` symbol in the `Analog_ADC` KiCad library. The specific modifications made were:

- The SDO pin was changed from the Output pin type to the Tri-State pin type

The symbol for `NC7SZ125` was created by Ethan Li as a copy of the `74LVC1G125` symbol in the `74xGxx` KiCad library, without any modifications besides renaming the symbol.

All symbols created as modifications of symbols in the KiCad libraries are copyright Prakash Lab and the Octopi project contributors, and those symbols are licensed under the [Creative Commons CC-BY-SA 4.0 License](LICENSE.CC-BY-SA) as required by the KiCad [libraries license](https://kicad.org/libraries/license/).

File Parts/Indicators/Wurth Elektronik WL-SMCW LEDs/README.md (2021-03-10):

# Wurth Elektronik WL-SMCW

Documentation and specifications for Wurth Elektronik WL-SMCW LEDs

## License

The PDF files in this directory are copyright Wurth Elektronik.

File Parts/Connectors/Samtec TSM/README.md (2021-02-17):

# Samtec TSM

Documentation, specifications, 3-D models, and footprints for Samtec TSM connectors

## License

The PDF files in this directory are copyright Samtec. The STP files in this directory were made available by Samtec and was originally published by the PARTcommunity/PARTserver powered by Cadenas, with terms of use available at http://www.cadenas.de/terms-of-use-3d-cad-models. The KICAD_MOD file in this directory was published by SnapEDA and is copyright SnapEDA, with the following [terms and conditions](https://www.snapeda.com/about/terms/): "Individual Design Files downloaded from SnapEDA are licensed to you pursuant to [Creative Commons Attribution-ShareAlike 4.0 International License (CC BY-SA)](https://creativecommons.org/licenses/by-sa/4.0/) ("Creative Commons License") and pursuant to the Design Exception 1.0 set forth below in Subsection 4.2. The Creative Commons License allows you to use Design Files downloaded from SnapEDA for commercial and personal purposes free of charge, and to make derivative works as set forth below."

Ethan Li created the FCStd, STEP, and WRL files in this directory using the STP files in this directory. Those files are copyright Prakash Lab and the Octopi project contributors, and those files are licensed under the [Solderpad Hardware License v2.1](/LICENSE) (the “License”); you may not use files except in compliance with the License, or, at your option, the [Apache License version 2.0](/LICENSE.Apache). You may obtain a copy of the License at https://solderpad.org/licenses/SHL-2.1/

Unless required by applicable law or agreed to in writing, any work distributed under the License is distributed on an “AS IS” BASIS, WITHOUT WARRANTIES OR CONDITIONS OF ANY KIND, either express or implied. See the License for the specific language governing permissions and limitations under the License.

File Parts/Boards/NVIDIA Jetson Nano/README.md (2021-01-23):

# NVIDIA Jetson Nano

Documentation, specifications, and 3-D models for the NVIDIA Jetson Nano Developer Kit

## License

The PDF files and STP file in this directory are copyright NVIDIA Corporation and have been released for use by the NVIDIA Jetson community.

Ethan Li created the FCStd, STEP, and WRL files in this directory using the STP file in this directory. Those files are copyright Prakash Lab and the Octopi project contributors, and those files are licensed under the [Solderpad Hardware License v2.1](/LICENSE) (the “License”); you may not use files except in compliance with the License, or, at your option, the [Apache License version 2.0](/LICENSE.Apache). You may obtain a copy of the License at https://solderpad.org/licenses/SHL-2.1/

Unless required by applicable law or agreed to in writing, any work distributed under the License is distributed on an “AS IS” BASIS, WITHOUT WARRANTIES OR CONDITIONS OF ANY KIND, either express or implied. See the License for the specific language governing permissions and limitations under the License.

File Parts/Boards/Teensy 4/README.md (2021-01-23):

# Teensy 4

Documentation, specifications, and 3-D models for the Teensy 4

## License

The IMXRT1060 PDF files in this directory are copyright NXP and have been released to enable system and software implementers to use NXP products. The Pinout Card PDF file and PNG file in this directory are copyright PJRC.

The STP and file in this directory was published by Karim Korish on GrabCAD at https://grabcad.com/library/teensy-4-1-development-board-1 . According to its terms of use, GrabCAD makes its models to users available under "a worldwide, non-exclusive, royalty-free, fully-paid, perpetual, irrevocable, non-sublicensable, non-assignable, and non-transferable license to use, reproduce, copy, modify, adapt, arrange, translate, and create derivative works of such User Submissions for such user's own benefit and non-commercial, internal use".

Ethan Li created the FCStd, STEP, and WRL files in this directory using the STP file in this directory. Those files are copyright Prakash Lab and the Octopi project contributors, and those files are licensed under the [Solderpad Hardware License v2.1](/LICENSE) (the “License”); you may not use files except in compliance with the License, or, at your option, the [Apache License version 2.0](/LICENSE.Apache). You may obtain a copy of the License at https://solderpad.org/licenses/SHL-2.1/

Unless required by applicable law or agreed to in writing, any work distributed under the License is distributed on an “AS IS” BASIS, WITHOUT WARRANTIES OR CONDITIONS OF ANY KIND, either express or implied. See the License for the specific language governing permissions and limitations under the License.

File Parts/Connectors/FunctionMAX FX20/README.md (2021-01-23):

# FunctionMAX FX20

Documentation, specifications, and 3-D models for Hirose FunctionMAX FX20 connectors

## License

The PDF files in this directory are copyright Hirose Electric. The STP file in this directory is copyright Hirose Electric and is released only for personal, non-commercial use. This project has received permission from Hirose to redistribute these STP files for use in the Squid project, for making mechanical CAD renderings and for non-commercial uses.

Ethan Li created the FCStd, STEP, and WRL files in this directory using the STP file in this directory. Those files are copyright Prakash Lab and the Octopi project contributors, and those files are licensed under the [Solderpad Hardware License v2.1](/LICENSE) (the “License”); you may not use files except in compliance with the License, or, at your option, the [Apache License version 2.0](/LICENSE.Apache). You may obtain a copy of the License at https://solderpad.org/licenses/SHL-2.1/

Unless required by applicable law or agreed to in writing, any work distributed under the License is distributed on an “AS IS” BASIS, WITHOUT WARRANTIES OR CONDITIONS OF ANY KIND, either express or implied. See the License for the specific language governing permissions and limitations under the License.

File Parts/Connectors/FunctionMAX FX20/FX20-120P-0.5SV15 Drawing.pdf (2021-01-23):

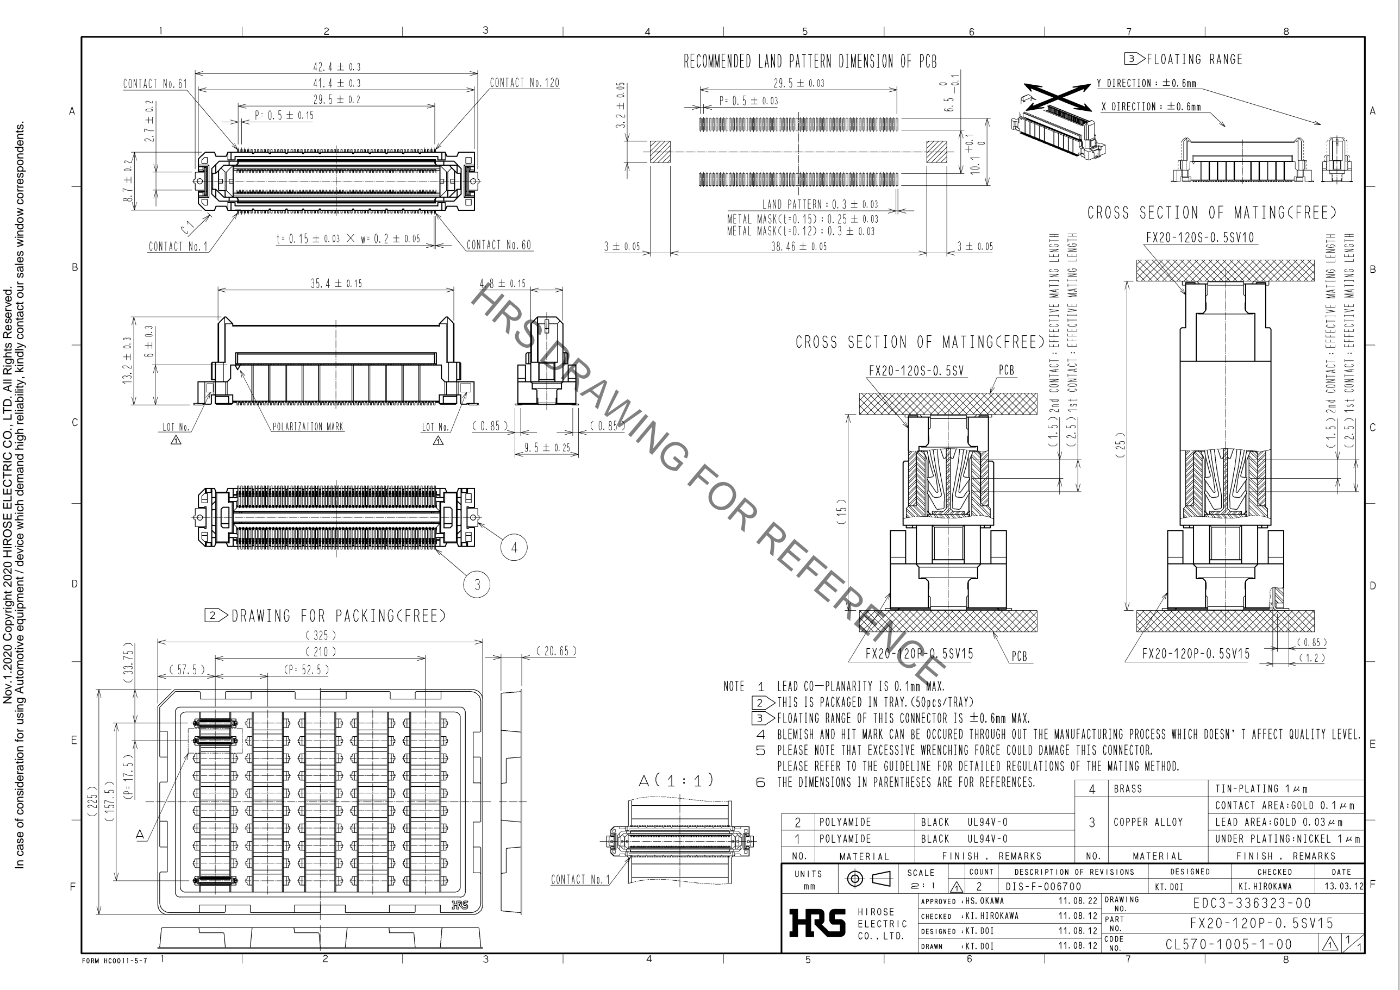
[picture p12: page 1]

HRS DRAWING FOR REFERENCE

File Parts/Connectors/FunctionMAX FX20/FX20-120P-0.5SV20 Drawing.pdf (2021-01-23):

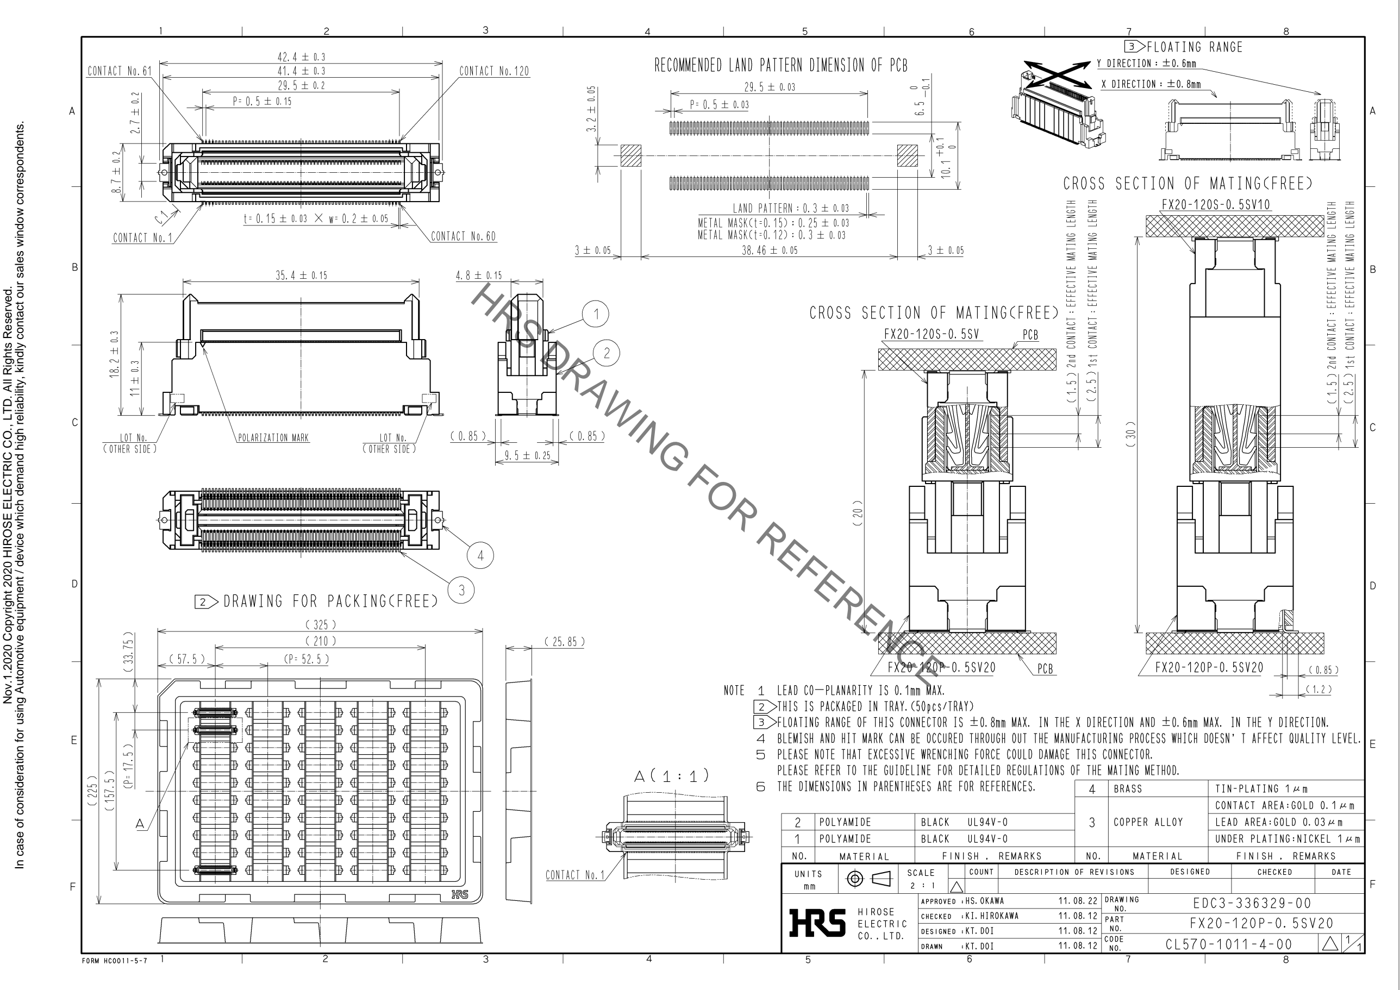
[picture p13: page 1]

HRS DRAWING FOR REFERENCE

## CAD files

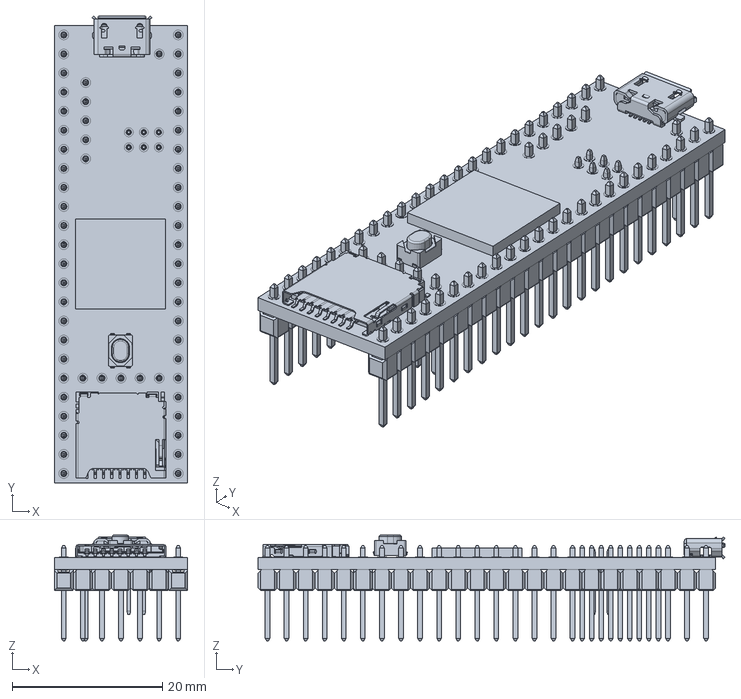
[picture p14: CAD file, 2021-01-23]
Parts/Boards/Teensy 4/Teensy 4.1.FCStd
17.8 x 62.2 x 14.1 mm

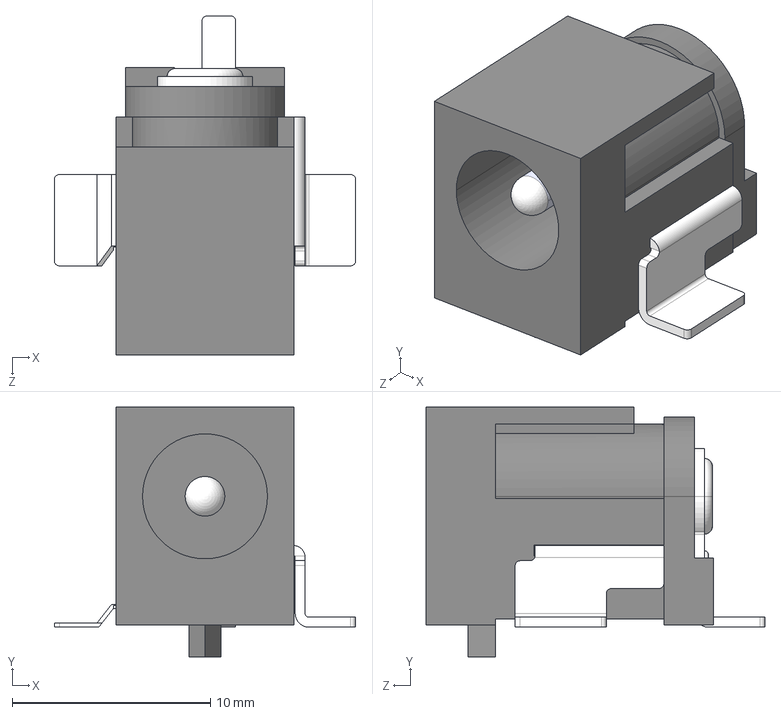
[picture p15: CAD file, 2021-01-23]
Parts/Connectors/CUI PJ/PJ-036AH-SMT-TR.stp
15.2 x 12.6 x 17.1 mm

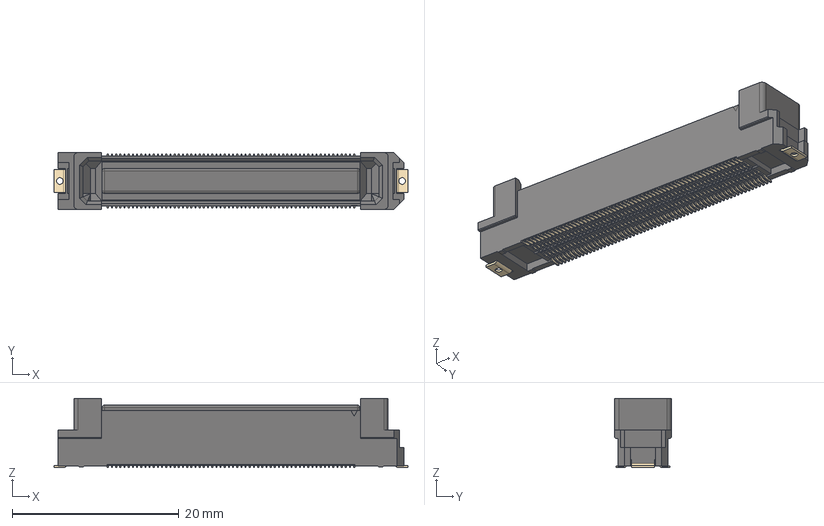
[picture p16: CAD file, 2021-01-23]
Parts/Connectors/FunctionMAX FX20/FX20-120S-0.5SV.step
42.4 x 6.80 x 8.30 mm

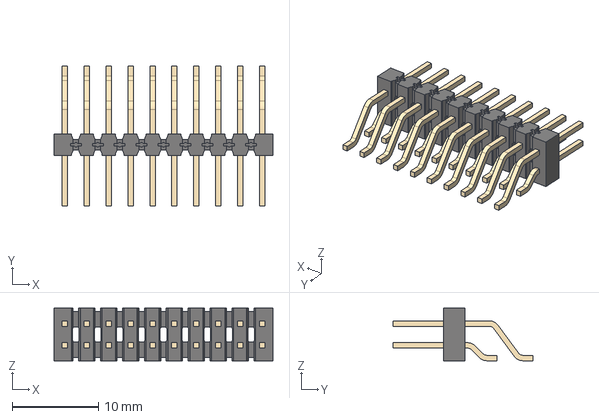
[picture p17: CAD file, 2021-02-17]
Parts/Connectors/Samtec TSM/TSM_110_01_T_DH.step
25.4 x 16.3 x 6.10 mm

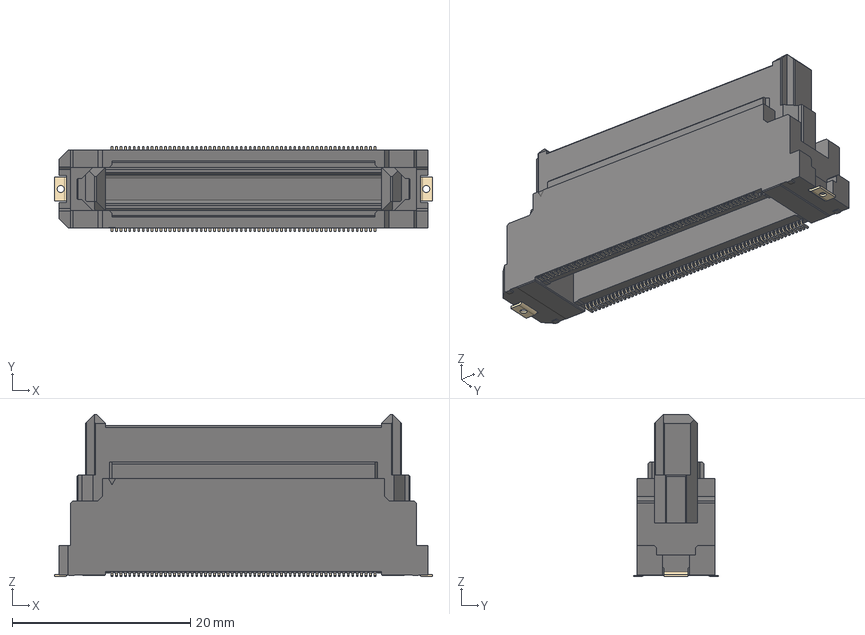
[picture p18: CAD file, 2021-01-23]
Parts/Connectors/FunctionMAX FX20/FX20-120P-0.5SV20.step
42.4 x 9.50 x 18.2 mm

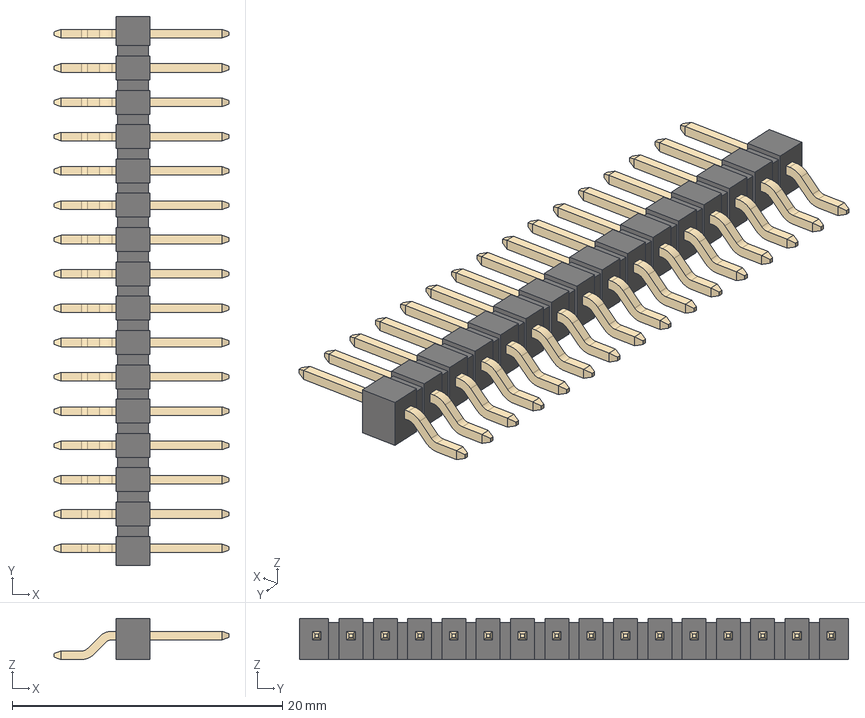
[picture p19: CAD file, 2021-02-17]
Parts/Connectors/Samtec TSM/TSM_116_01_T_SH.step
13.0 x 40.6 x 3.05 mm

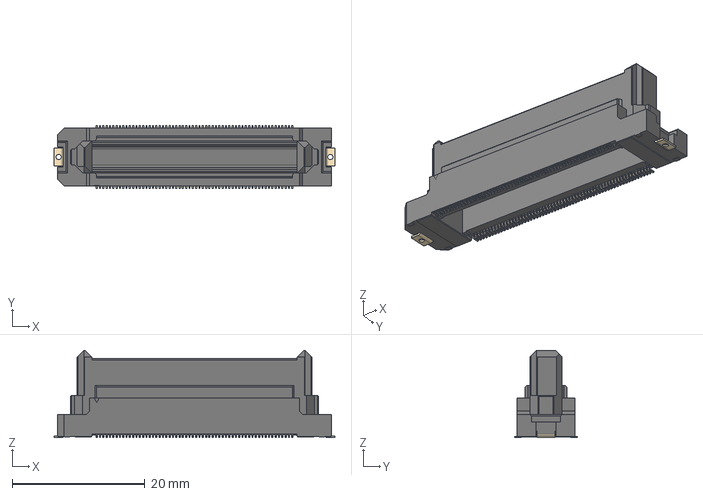
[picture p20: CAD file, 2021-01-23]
Parts/Connectors/FunctionMAX FX20/FX20-120P-0.5SV15.step
42.4 x 9.50 x 13.2 mm

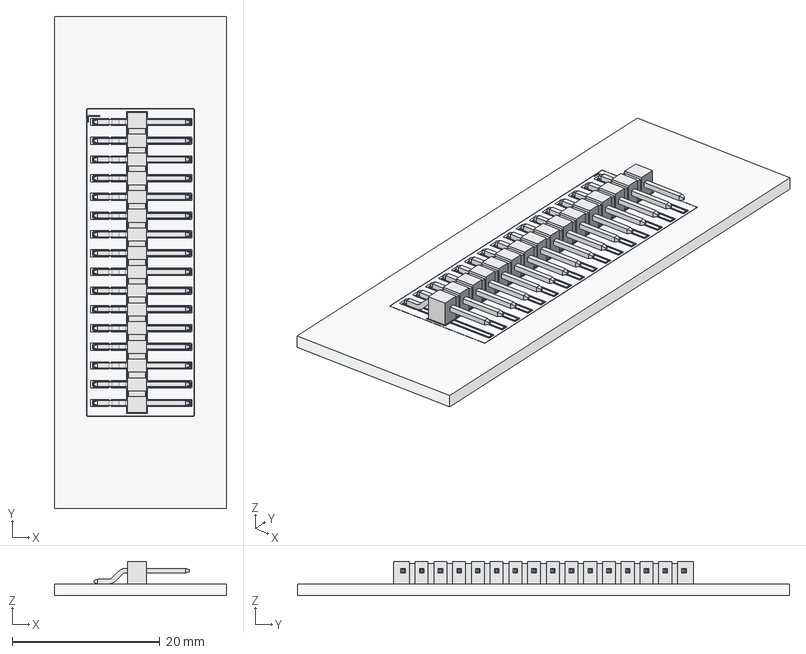
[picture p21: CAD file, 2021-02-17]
Parts/Connectors/Samtec TSM/TSM-116-01-X-SH.FCStd
23.4 x 66.7 x 4.65 mm
FCrtYd
FFab
FrontSilk
TopPads
Pcb
TSM_116_01_T_SH

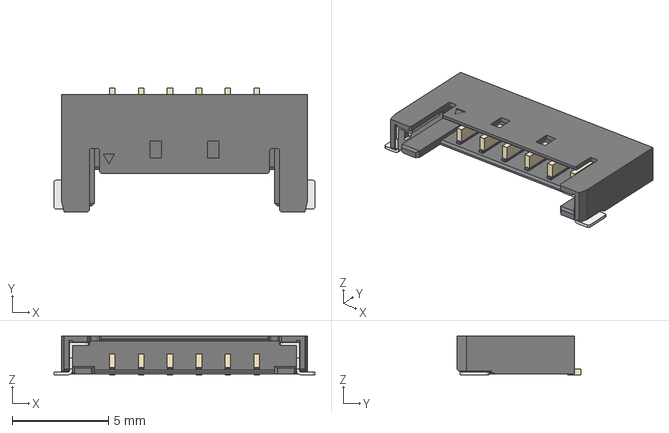
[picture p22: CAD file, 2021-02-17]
Parts/Connectors/Molex Pico-Lock 1.5mm/504050-0691.step
13.6 x 6.44 x 2.00 mm

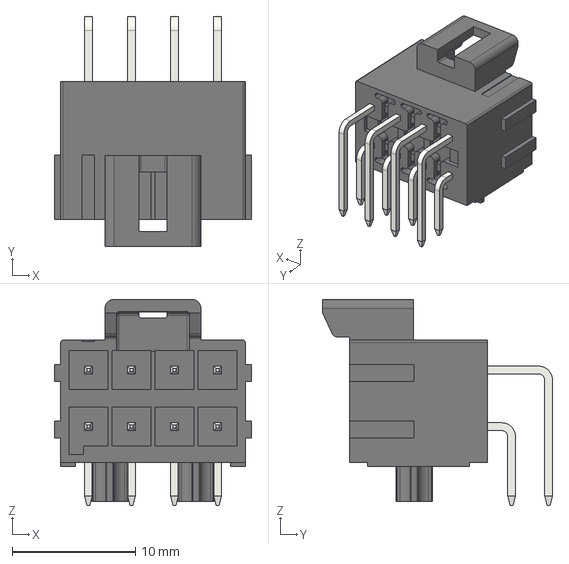
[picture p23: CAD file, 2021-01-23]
Parts/Connectors/Molex Ultra-Fit/172316-1108.step
16.0 x 18.7 x 16.8 mm

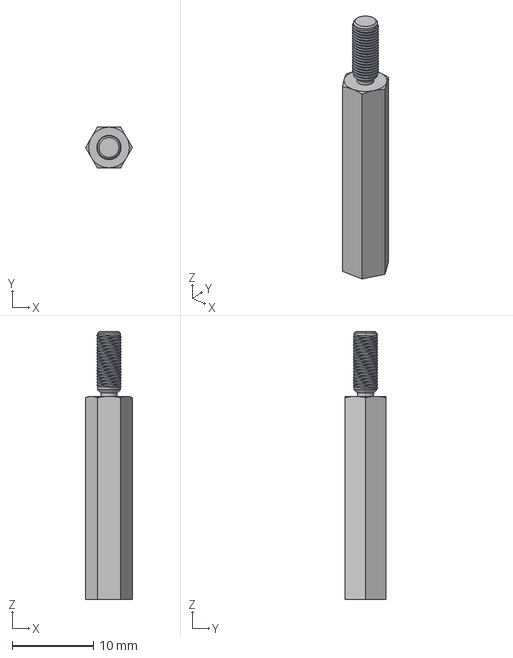
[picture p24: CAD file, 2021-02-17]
Parts/Fasteners/Keystone Standoffs/24342.step
5.77 x 5.00 x 33.0 mm

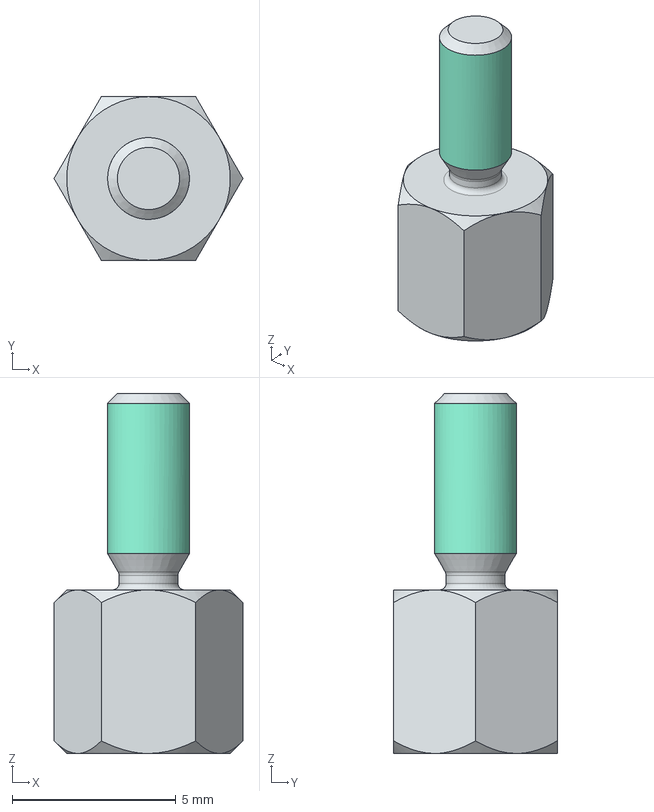
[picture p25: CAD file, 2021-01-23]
Parts/Fasteners/Wurth Elektronik Standoffs/971050154.stp
5.77 x 5.00 x 11.0 mm

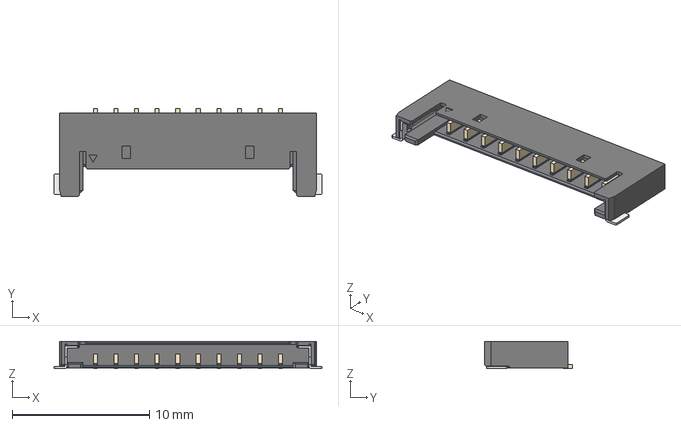
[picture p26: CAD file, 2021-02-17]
Parts/Connectors/Molex Pico-Lock 1.5mm/504050-1091.step
19.6 x 6.44 x 2.00 mm

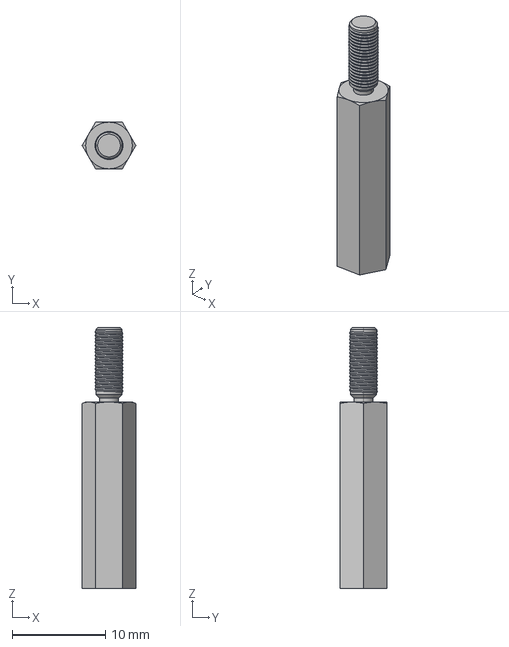
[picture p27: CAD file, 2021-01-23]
Parts/Fasteners/Keystone Standoffs/24341.step
5.77 x 5.00 x 28.0 mm

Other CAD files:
Parts/Connectors/CUI PJ/CUI_DEVICES_PJ-036AH-SMT-TR.step
Parts/Connectors/Samtec TSM/TSM-110-01-X-DH.stp
Parts/Fasteners/Wurth Elektronik Standoffs/970200154.step
Parts/Fasteners/Keystone Standoffs/24339.step
ODSv1.0.0/ODSv1.0.0.blend
Parts/Connectors/CUI PJ/PJ-036AH-SMT-TR.FCStd
Parts/Connectors/FunctionMAX FX20/FX20-120P-0.5SV15.FCStd
Parts/Connectors/FunctionMAX FX20/FX20-120P-0.5SV15.stp
Parts/Connectors/FunctionMAX FX20/FX20-120P-0.5SV20.FCStd
Parts/Connectors/FunctionMAX FX20/FX20-120P-0.5SV20.stp
Parts/Connectors/FunctionMAX FX20/FX20-120S-0.5SV.FCStd
Parts/Connectors/FunctionMAX FX20/FX20-120S-0.5SV.stp
Parts/Connectors/Molex Pico-Lock 1.5mm/504050-0691.FCStd
Parts/Connectors/Molex Pico-Lock 1.5mm/504050-0691.stp
Parts/Connectors/Molex Pico-Lock 1.5mm/504050-1091.FCStd
Parts/Connectors/Molex Pico-Lock 1.5mm/504050-1091.stp
Parts/Connectors/Molex Ultra-Fit/172316-1108.FCStd
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

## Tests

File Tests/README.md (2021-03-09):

# Tests

Basic tests for board provided by the Octopi Driver Stack

## Background

This directory contains unit tests for board provided by ODSv1.0.0. These tests are just for verification of basic functionalities to confirm that the board was designed and assembled correctly, and are roughly equivalent to example sketches provided by the Arduino IDE. These tests are implemented as Arduino sketches, and manual action is needed to follow test procedures.

## Usage

Test procedures and usage instructions for each test are provided by the README.md files in each subdirectory of this directory.

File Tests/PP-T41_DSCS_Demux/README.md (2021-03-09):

# PP-T41 DSCS Demultiplexing Test _(PP-T41_DSCS_Demux)_

Device switcher CS demultiplexing test for PP-T41

This test cycles through every demultiplexed DSCS line of the PP-T41 plane and generates a square wave on that line, one at a time; it cycles to the next demultiplexed DSCS line when a newline (`\n`) is received as input through the serial connection.

## Background

This unit test allows for confirmation that [ODSv1.0.0-PP-T41](../../ODSv1.0.0-PP-T41) can demultiplex the signal from DSCS over the demultiplexed DSCS lines DSCS0, DSCS1, ..., DSCS15 in the backbone.

## Install

As this is an Arduino sketch intended to be uploaded to the Teensy 4.1, the Arduino IDE and Teensyduino should be installed in [the standard way](https://www.pjrc.com/teensy/td_download.html). Then, download the Arduino sketch in this directory with the Arduino IDE, configure the Arduino IDE to upload the sketch to your Teensy 4.1 board, and upload the sketch.

## Usage

As this test generates output waveforms on the GPIO pins of the Teensy, verification of functionality will need to be done with an oscilloscope (or instrument with equivalent functionality for measuring digital voltage waveforms), and the probe(s) will need to be manually be moved between GPIO pins.

This test can be used with the following test procedure:

### Verification of Standalone Functionality

Hardware setup: the Teensy 4.1 is plugged into an ODSv1.0.0-PP-T41 board, which is stacked with an ODSv1.0.0-BP-Jmp board on top. Then the oscilloscope probe(s) should be applied to the pins of header J1 of the ODSv1.0.0-BP-Jmp board, (which is on the bottom face of the board, at the front edge), as well as the SPI_DSCS0 pin of Molex Pico-Lock connector J8 of the ODSv1.0.0-PP-T41 board (which is at the right edge, labeled `HB-*: SPI`). This allows verification that ODSv1.0.0-PP-T41 is correctly demultiplexing the DSCS line and that the backbone connectors are correctly passing signals over the demultiplexed DSCS lines.

Upload the Arduino sketch to the Teensy board, then open the Serial Monitor. Configure it to use a baud rate of 115200 and use Newline as the line ending. You should see a message asking you to confirm that you have configured your Serial Monitor correctly, and instructing you to press the Enter key to begin the test. Before pressing Enter, put an oscilloscope probe on the SPI_DSCS0 pin. You should see that this pin is floating; and every pin on header J1 of ODSv1.0.0-BP-Jmp should be floating.

Once you press Enter, the test will begin. The Teensy board will begin outputting a 1 kHz square wave to DSCS0, and you should be able to see this on the oscilloscope. If you move the oscilloscope probe to any other pin, which will be on header J1 of ODSv1.0.0-BP-Jmp, it should still be floating. Each time you press Enter, the Teensy will stop outputting a square wave on the current pin, it will start outputting a square wave on the next pin (in order of DSCS0, DSCS1, DSCS2, ..., DSCS15, DSCS0, DSCS1, ...), and it will print a message to the Serial Monitor announcing this; you should see the square wave if and only if you move the oscilloscope probe to the corresponding pin indicated by the announcement on the Serial Monitor, but not on any other pin.

### Verification of Stacked Functionality

Hardware setup: the same as in the previous test, and any arbitrary number of other boards are stacked between the ODSv1.0.0-PP-T41 board and the ODSv1.0.0-BP-Jmp board. This allows verification that all boards in the stack are correctly passing the demultiplexed DSCS signals.

This test should be done in the same way as the previous test procedure, and the behavior of the J1 header pins on ODSv1.0.0-BP-Jmp should be the same.

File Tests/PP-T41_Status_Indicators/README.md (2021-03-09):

# PP-T41 Status Indicators Test _(PP-T41_Status_Indicators)_

Status indicators test for PP-T41

This test cycles through every status indicator LED of PP-T41 and blinks that indicator once for one second, one at a time.

## Background

This unit test allows for confirmation that the Teensy can talk correctly over SPI to the MAX7317 chip on [ODSv1.0.0-PP-T41](../../ODSv1.0.0-PP-T41) and allows visual checking of the brightnesses of the status indicator LEDs.

## Install

As this is an Arduino sketch intended to be uploaded to the Teensy 4.1, the Arduino IDE and Teensyduino should be installed in [the standard way](https://www.pjrc.com/teensy/td_download.html). Then, download the Arduino sketch in this directory with the Arduino IDE, configure the Arduino IDE to upload the sketch to your Teensy 4.1 board, and upload the sketch.

## Usage

As this test blinks the status indicator LEDs, verification of functionality will need to be done by visual inspection of the status indicator LEDs.

This test can be used with the following test procedures, for different purposes:

### Verification of Standalone Functionality

Hardware setup: the Teensy board is plugged into the ODSv1.0.0-PP-T41 board. This allows verification that PP-T41 operates correctly on its own.

Upload the Arduino sketch to the Teensy board. You should start to see the status indicator LEDs start blinking, one after the next.

### Verification of Stacked Functionality

Hardware setup: the Teensy board is plugged into the ODSv1.0.0-PP-T41 board, and any arbitrary number of other boards are stacked on top of the ODSv1.0.0-PP-T41 board. This allows verification that the status indicator LEDs of the PP-T41 board are independent from the status indicator LEDs of any other board.

This test should be done in the same way as the previous test procedure, and the behavior of the status indicator LEDs should be the same. Only the status indicator LEDs on PP-T41 should blink; status indicator LEDs on other boards should not blink.

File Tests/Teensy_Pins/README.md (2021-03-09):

# Teensy Pins Test _(Teensy_Pins)_

GPIO connectivity test for the backbone

This test cycles through every GPIO pin of the Teensy 4.1 and generate a square wave on that pin, one at a time; it cycles to the next GPIO pin when a newline (`\n`) is received as input through the serial connection.

## Background

This unit test allows for confirmation that the non-interplane signal lines on [ODSv1.0.0-PP-T41](../../ODSv1.0.0-PP-T41) and the backbone are connected to the Teensy 4.1 microcontroller on the processing plane.

## Install

As this is an Arduino sketch intended to be uploaded to the Teensy 4.1, the Arduino IDE and Teensyduino should be installed in [the standard way](https://www.pjrc.com/teensy/td_download.html). Then, download the Arduino sketch in this directory with the Arduino IDE, configure the Arduino IDE to upload the sketch to your Teensy 4.1 board, and upload the sketch.

## Usage

As this test generates output waveforms on the GPIO pins of the Teensy, verification of functionality will need to be done with an oscilloscope (or instrument with equivalent functionality for measuring digital voltage waveforms), and the probe(s) will need to be manually be moved between GPIO pins.

This test can be used with the following test procedures, for different purposes:

### Verification of Standalone Teensy Functionality

Hardware setup: the Teensy 4.1 is connected to the computer by a USB cable, but the Teensy board itself is not plugged into anything. Then the oscilloscope probe(s) should be applied to the Teensy's header pins. This allows verification that the Teensy 4.1 is able to generate the correct outputs on its own pins.

Upload the Arduino sketch to the Teensy board, then open the Serial Monitor. Configure it to use a baud rate of 115200 and use Newline as the line ending. You should see a message asking you to confirm that you have configured your Serial Monitor correctly, and instructing you to press the Enter key to begin the test. Before pressing Enter, put an oscilloscope probe on pin 0 of the Teensy, following the pin numbering scheme of the official [Teensy 4.1 pinout diagram](../../Parts/Board/Teensy%204/Pinout%20Card.pdf). You should see that this pin has a constant voltage of 0 V; in fact, every pin should start out with a constant voltage of 0 V.

Once you press Enter, the pin test will begin. The Teensy board will begin outputting a 1 kHz square wave to pin 0, and you should be able to see this on the oscilloscope. If you move the oscilloscope probe to pin 1 or any other pin, it should still have a constant voltage of 0 V. Each time you press Enter, the Teensy will stop outputting a square wave on the current pin, it will start outputting a square wave on the next pin (in order of 0, 1, 2, 3, ..., 39, 40, 41, 0, 1, 2, 3, ...), and it will print a message to the Serial Monitor announcing this; you should see the square wave if and only if you move the oscilloscope probe to the corresponding pin indicated by the announcement on the Serial Monitor, but not on any other pin.

### Verification of Standalone ODSv1.0.0-PP-T41 Functionality

Hardware setup: the Teensy 4.1 is plugged into an ODSv1.0.0-PP-T41 board, which is not connected to any other boards. Then the oscilloscope probe(s) should be applied to the solder joints of the Teensy's header pins. This allows verification that ODSv1.0.0-PP-T41 is not incorrectly pulling any of the Teensy's pins to 0 V or 3.3 V.

This test should be done in the same way as the previous test procedure, except the hardware setup for this test involves plugging in the Teensy's longer male header pins, which were exposed for the oscilloscope probe(s) in the previous test procedure, into the female headers of a PP-T41 PCB. So in this test, the probe(s) should instead be used to measure the short parts of the Teensy's male header pins - the parts which are soldered to the Teensy board itself.

If everything is working according to specifications, you should see the same results as the previous test procedure.

### Verification of ODSv1.0.0-PP-T41 Backbone GPIO functionality

Hardware setup: the Teensy 4.1 is plugged into an ODSv1.0.0-PP-T41 board, which is stacked with another ODSv1.0.0-PP-T41 board underneath, so that the Teensy 4.1 is between the PP-T41 PCBs; note that the Teensy 4.1 is a too tall to fit perfectly in the space between the PP-T41 PCBs, so those PCBs will at a slight angle to each other. The lower ODSv1.0.0-PP-T41 board should not have a Teensy in it. Then the oscilloscope probe(s) should be applied to the female headers of the lower ODSv1.0.0-PP-T41 board for holding the Teensy board (J3 & J4) - it is recommended to connect the oscilloscope probe(s) to male-to-male jumper wires, which can then be plugged into the female headers. This allows verification that the backbone connectors are correctly passing signals and that they are not incorrectly pulling any of the Teensy's pins to 0 V or 3.3 V.

This test should be done in the same way as the previous test procedure, except the hardware setup for this test involves connecting a second ODSv1.0.0-PP-T41 PCB which covers over the Teensy board. So in this test, the probe(s) should instead be used to measure the female headers at positions J3 and J4 of the second PP-T41 PCB.

If everything is working according to specifications, you should see the same results as the previous test procedure, but with the following differences:

- When the Teensy is generating a square wave on pin 30 or 31, you will not see a 1 kHz square wave on your oscilloscope probe; instead, the oscilloscope should show a waveform which looks as if the probe is not connected to anything. This is because pins 30 and 31 of the Teensy are not exposed through the backbone.

### Verification of ODSv1.0.0-BP-Jmp GPIO Breakout Functionality

Hardware setup: the Teensy 4.1 is plugged into an ODSv1.0.0-PP-T41 board, which is stacked with an ODSv1.0.0-BP-Jmp board on top. Then the oscilloscope probe(s) should be applied to the header pins of the ODSv1.0.0-BP-Jmp board. This allows verification that ODSv1.0.0-BP-Jmp and the backbone connectors are correctly passing signals and that they are not incorrectly pulling any of the Teensy's pins to 0 V or 3.3 V.

This test should be done in the same way as the previous test procedure, except the hardware setup for this test involves stacking the BP-Jmp PCB on top, and you will be using the oscilloscope probe(s) to probe the header pins of BP-Jmp. Because many header pin labels do not correspond to the Teensy pin numbers, refer to the "Teensy Pin Mappings" subsection of [/ODSv1.0.0-BP-Jmp/README.md](../../ODSv1.0.0-BP-Jmp/README.md) to locate the pins you should probe with your oscilloscope probe(s).

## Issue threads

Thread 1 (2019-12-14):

Add corner fillets

ethanjli, 2019-12-14:
Add fillets to the corners of the board so that the corners can't accidentally cut anything

ethanjli, 2020-03-12:
Added in ODS v0.2.0.

Closed 2020-03-12.

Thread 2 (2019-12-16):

Fix position of silkscreen labels for 3.3V screw terminals

ethanjli, 2019-12-16:
They are currently misaligned by one unit in the top left of the board.

Closed 2021-01-02.

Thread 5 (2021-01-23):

Fix silkscreens on ODSv1.0.0-PP-T41

ethanjli, 2021-01-23:
The following corrections need to be made to the layout of ODSv1.0.0-PP-T41:

- The reference labels for J1 and J2 should be moved to the right of the connector, so that it doesn't impinge on the board title area. This should also be done in ODSv1.0.0-BT. In the version submitted to PCBway for fab, it was correct, but a later change which renamed the footprint and footprint library seemed to have messed up the position of the reference label.
- J3 is missing a label for GND in its first pin.

Closed 2021-01-30.

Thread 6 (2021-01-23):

Make kicad-exports workflow use workflow_dispatch

ethanjli, 2021-01-23:
When manually triggering the kicad-exports workflow, it should be possible to specify which boards to export docs for - i.e. short-circuiting the logic of the `diff` step of the `diff-boards` job by overriding the value of its output.

Closed 2021-01-23.

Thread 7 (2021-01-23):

Allow generating kicad-exports for variants

ethanjli, 2021-01-23:
When manually triggering the kicad-exports workflow, it should be possible to specify a variant of the board to create the BOMs and position files for. We will also need to modify the columns of the BOM fields of the board to support this - but it's not clear to me yet how this would interact with the current system of using DNP in the value fields to set the default variant.

Closed 2021-01-30.

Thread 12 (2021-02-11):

Arduino sketch unit tests for SPI chip-select multiplexing

ethanjli, 2021-02-11:
A suite of Arduino sketches should be written to exercise the SPI chip-select multiplexing functionalities. We can start with a simple blink sketch with only PP-T41. We should also write some tests for BP-Jmp, once that arrives. Tests for functionality of other planes might be out of scope of this repo, if they are complex (e.g. if they require writing nontrivial drivers); tests in this repo should be limited to the ODSv1.0.0 stacking architecture.

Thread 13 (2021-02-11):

Design a laser-cut baseplate

ethanjli, 2021-02-11:
The standoff legs under PP-T41 are long enough that they could break if they aren't stabilized by baseplate underneath. We could add a laser-cut hole for the heatsink+fan, and we could also add mounting holes for optical table screw grids, as well as for a Raspberry Pi and for a Jetson Nano (offset so that cables stick out much less or not at all); and we could add some engraved labels documenting the stack. We could also design a cap plate on top to protect the stacking connector, potentially with mounting holes for HMI boards; and we could add some engraved labels documenting the stack.

We could design two alternates: one which follows the 150 mm x 150 mm footprint format, and one with overhangs (which would allow acrylic sheet bending to be used to make a case held in place by the overhangs)

ethanjli, 2021-02-24:
I've prototyped a minimal baseplate enclosure as BE-Minv0.1.0, [in Onshape](https://cad.onshape.com/documents/4fb7feb5bae3d3626f4b1533/w/fe4d932186ace8316f07352d/e/5d2fb6e19c538a483a3bb1a2); it fits nicely. However, text (e.g. from Onshape) doesn't export correctly into DXF for laser-cutter engraving and has to be re-added properly in Inkscape. The next step is to investigate whether FreeCAD can do better.

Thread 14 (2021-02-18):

Reduce brightnesses of indicator LEDs

ethanjli, 2021-02-18:
The indicator LEDs are too bright:
- The brightnesses of the blue power indicator LEDs in the backbone section of every plane, as well as the power indicator LEDs on PP-T41, should be reduced by half. We might also be able to reduce cost by replacing them with green LEDs, as long as current draw is sufficiently low.
- The brightnesses of the status indicator LEDs in the backbone section of every plane are still TBD.

ethanjli, 2021-02-25:
The brightnesses of the status LEDs in the backbone section seem to be good, though for the normal and warning indicators we may want to reduce brightness a bit.

It seems that the availability of yellow, orange, and blue LEDs may not be so good; and the blue LEDs are twice as expensive as the other LEDs. So maybe we should switch to a different product line, e.g. Wurth Elektronik.

ethanjli, 2021-03-10:
Also, the silkscreen LED polarity symbols are too small to be readable, so they should be enlarged.

Closed 2021-03-10.

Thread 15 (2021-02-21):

Test points for non-backbone pins on PP-T41

ethanjli, 2021-02-21:
Currently, the Teensy pins 30 & 31 (corresponding to MSCS and DSCS) are not exposed over the backbone. This means that it's not so easy to probe those pins with a logic analyzer, unless a special Teensy is soldered with extra-long header pins which stick out the top to allow jumper wires to be plugged in; otherwise I have to hold a jumper wire to pin 2 of U1 (the MAX7317 chip).

It would be really helpful to have a place to solder header pins exposing MSCS, DSCS, and DSCS0 in the backbone section of PP-T41, so that we can plug in jumper wires (e.g. for a logic analyzer). We can place the footprint for the header on the underside of the board in the front right region. We would probably want to leave it off all BOM variants.

Closed 2021-03-09.

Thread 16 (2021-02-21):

MAX7317 DOUT pin needs a buffer for CIPO to be tri-state

ethanjli, 2021-02-21:
It turns out that page 5 of the [MAX7317 datasheet](https://datasheets.maximintegrated.com/en/ds/MAX7317.pdf) has a note buried in a paragraph saying:

> Note that the SPI protocol expects DOUT to be high impedance when the MAX7317 is not being accessed; DOUT on the MAX7317 is never high impedance. Go to https://pdfserv.maximintegrated.com/en/an/AN1879.pdf for ways to convert the MAX7317 to tri-state, if required.

We absolutely need this, and I totally missed this note in designing ODSv1.0.0-PP-T41v0.1.0. As [Maxim AN1879](https://pdfserv.maximintegrated.com/en/an/AN1879) states, we'll need to add either an analog switch or a 3-state buffer between MAX7317's DOUT pin and the SPI CIPO pin, which should be gated on when the CS pin of the MAX7317 chip goes low, selecting the device and enabling DOUT at the same time. This change will need to be made on ODSv1.0.0-BT, ODSv1.0.0-BP-Jmp, and ODSv1.0.0-PP-T41. For ODSv1.0.0-PP-T41 and ODSv1.0.0-BT, it may be good enough just to disconnect the DOUT pin from CIPO.

Maxim AN1879 recommends MAX4595 or MAX4502 as suitable analog switches, or the NC7SZ125 or SN74AHC1G125 as suitable single 3-state buffers.

ethanjli, 2021-02-21:
As a temporary workaround on ODSv1.0.0-PP-T41v0.1.0, we can cut pin 14 of U1; however, this might be very difficult. For ODSv1.0.0-BP-Jmpv0.1.0, we'll need to avoid soldering pin 14 of U1, and we'll need to either avoid soldering pin 14 of U3 (which prevents us from using any ports of the I/O expander as inputs) or avoid populating U3 on the same board as U4 or U5.

ethanjli, 2021-03-10:
It would actually be useful to connect the MAX7317 DOUT pins to CIPO in the backbone section, as that allows us to read the 1-byte RAM register and the No-op register (allowing for automatic detection of plane addresses).

Closed 2021-03-19.

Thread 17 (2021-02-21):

Add pull-up resistors to open-drain logic output pins

ethanjli, 2021-02-21:
As described in the "Step 1" section of https://www.pjrc.com/better-spi-bus-design-in-3-steps/ , we need to ensure that chip-select pins have pull-up resistors so that interference or cross-talk can't spuriously activate an SPI device. If we try to be clever about where we place pull-up resistors to reduce the number of resistors needed (or to make them be part of ODSv1.0.0-BT), we will need to ensure that it works correctly when combined with our SPI CS multiplexing system (which makes demultiplexed CS pins float when they're not connected to DCS; and likewise for DSCS).

ethanjli, 2021-02-21:
We should also consider whether we need any pull-up resistors on the input pins to analog muxes, such as in the backbone

ethanjli, 2021-03-10:
We should add pull-up resistors on all demultiplexed DCS pins in BP-Jmp - probably next to the DCS headers.

Closed 2021-03-19.

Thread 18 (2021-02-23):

Restore 3D model of Teensy on PP-T41

ethanjli, 2021-02-23:
Sometime in #11 I had reset footprints of all components on PP-T41 without realizing the implications of doing so (loss of custom 3D model associations); while e7e4a1e restored the models, it did miss the Teensy 4.1 model. This needs to be added back, and 3D renders of ODSv1.0.0 need to be regenerated.

Closed 2021-03-09.

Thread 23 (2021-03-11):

Add a PWM driver to BP-Jmp

ethanjli, 2021-03-11:
The Teensy 4.1 features digital I/O, ADC, and PWM. Currently, BP-Jmp has standardized I/O peripherals which provide I/O expansion for digital I/O and for ADC, but not for PWM. In order to make it possible to use BP-Jmp to transition from purely using GPIO pins (for one-off prototyping) to using standardized I/O peripherals (for adapting firmware and testing the system in preparation for design of a new plane or peripheral board, for production), we should add a PWM driver. This should be usable for logic outputs (e.g. driving the gate pin of a MOSFET), so most LED PWM driver ICs are unsuitable. As far as I can tell, the only appropriate IC with reasonable availability is the [PCA 9685](https://www.nxp.com/products/power-management/lighting-driver-and-controller-ics/ic-led-controllers/16-channel-12-bit-pwm-fm-plus-ic-bus-led-controller:PCA9685). Because Adafruit produces a breakout board for this IC, there is also good Arduino library support for it. However, it only comes with an I2C interface (which runs at up to 1 MHz).

I propose that we put a PCA9685 on BP-Jmp; if possible, we should try to expose all 16 PWM outputs on a single 2x10 vertical header. Because this chip is large (28 pins), we might need to put it on the bottom of BP-Jmp; and/or we should consider whether to use the TSSOP package or the HVQFN package. NXP offers other, smaller PWM drivers, but they can't set PWM across the full range of 0 - 100% (their ranges end between 99% and 100%). We should also put a bus switch between its I2C pins and the I2C0 bus, to be controlled by DSCS3, to improve the modularity of BP-Jmp. We'll need to put pull-up resistors on this bus between the bus switch and the PCA9685; we'll also need to figure out whether we need to put pull-up resistors on I2C0 between the bus switch and the Teensy and, if so, where to put them.

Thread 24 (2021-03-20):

Increase spacing between pads of Hirose FunctionMax FX20 connectors

ethanjli, 2021-03-20:
PCBWay has reported that they cannot fab ODSv1.0.0-PP-T41v0.1.1 and ODSv1.0.0-BP-Jmpv0.2.0 in red because the spacing between the pads of the Hirose FunctionMax FX20 connectors is 0.2 mm rather than the minimum of 0.22 mm needed for red soldermask. I'm not sure why this is a problem now since it wasn't a problem earlier.

Currently the width of each pad is 0.3 mm, following the [FX20 datasheet](https://www.hirose.com/product/document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)'s t=0.12 specification. I now suspect that t may represent the thickness of the stencil, so that a thinner stencil requires a wider pad for the amount of solder needed. If we reduce the width of each pad to 0.25 mm, then we'll have 0.25 mm between each pad (allowing us to use red soldermask), and we may be able to reduce solder-bridging when we apply solderpaste ourselves using 0.12 mm stencils.

ethanjli, 2021-03-23:
Since we'll need to regenerate the footprints at https://github.com/prakashlab/octopi-driver-board/tree/develop/Parts/Connectors/Backbone_Connector_Hirose.pretty , while we're at it we might as well also fix the reference designators on the Fab layers.

After updating the footprints we should fix the 3D models for the footprints, in each PCB layout file.

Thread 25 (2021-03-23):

BOM Errors on BP-Jmpv0.2.0

ethanjli, 2021-03-23:
In BP-Jmp, row 12 of the BOM (36 resistors of value 2k) has incorrect values for Digikey ID, MPN, and Ordering URL; currently they are for 20k resistors (because I forgot to update those fields when I changed the value from 20k to 2k). The MPN for that row should actually be RC0603FR-072KL, the Digikey URL should actually be https://www.digikey.com/en/products/detail/yageo/RC0603FR-072KL/727009, and the Digikey ID should actually be 311-2.00KHRCT-ND.

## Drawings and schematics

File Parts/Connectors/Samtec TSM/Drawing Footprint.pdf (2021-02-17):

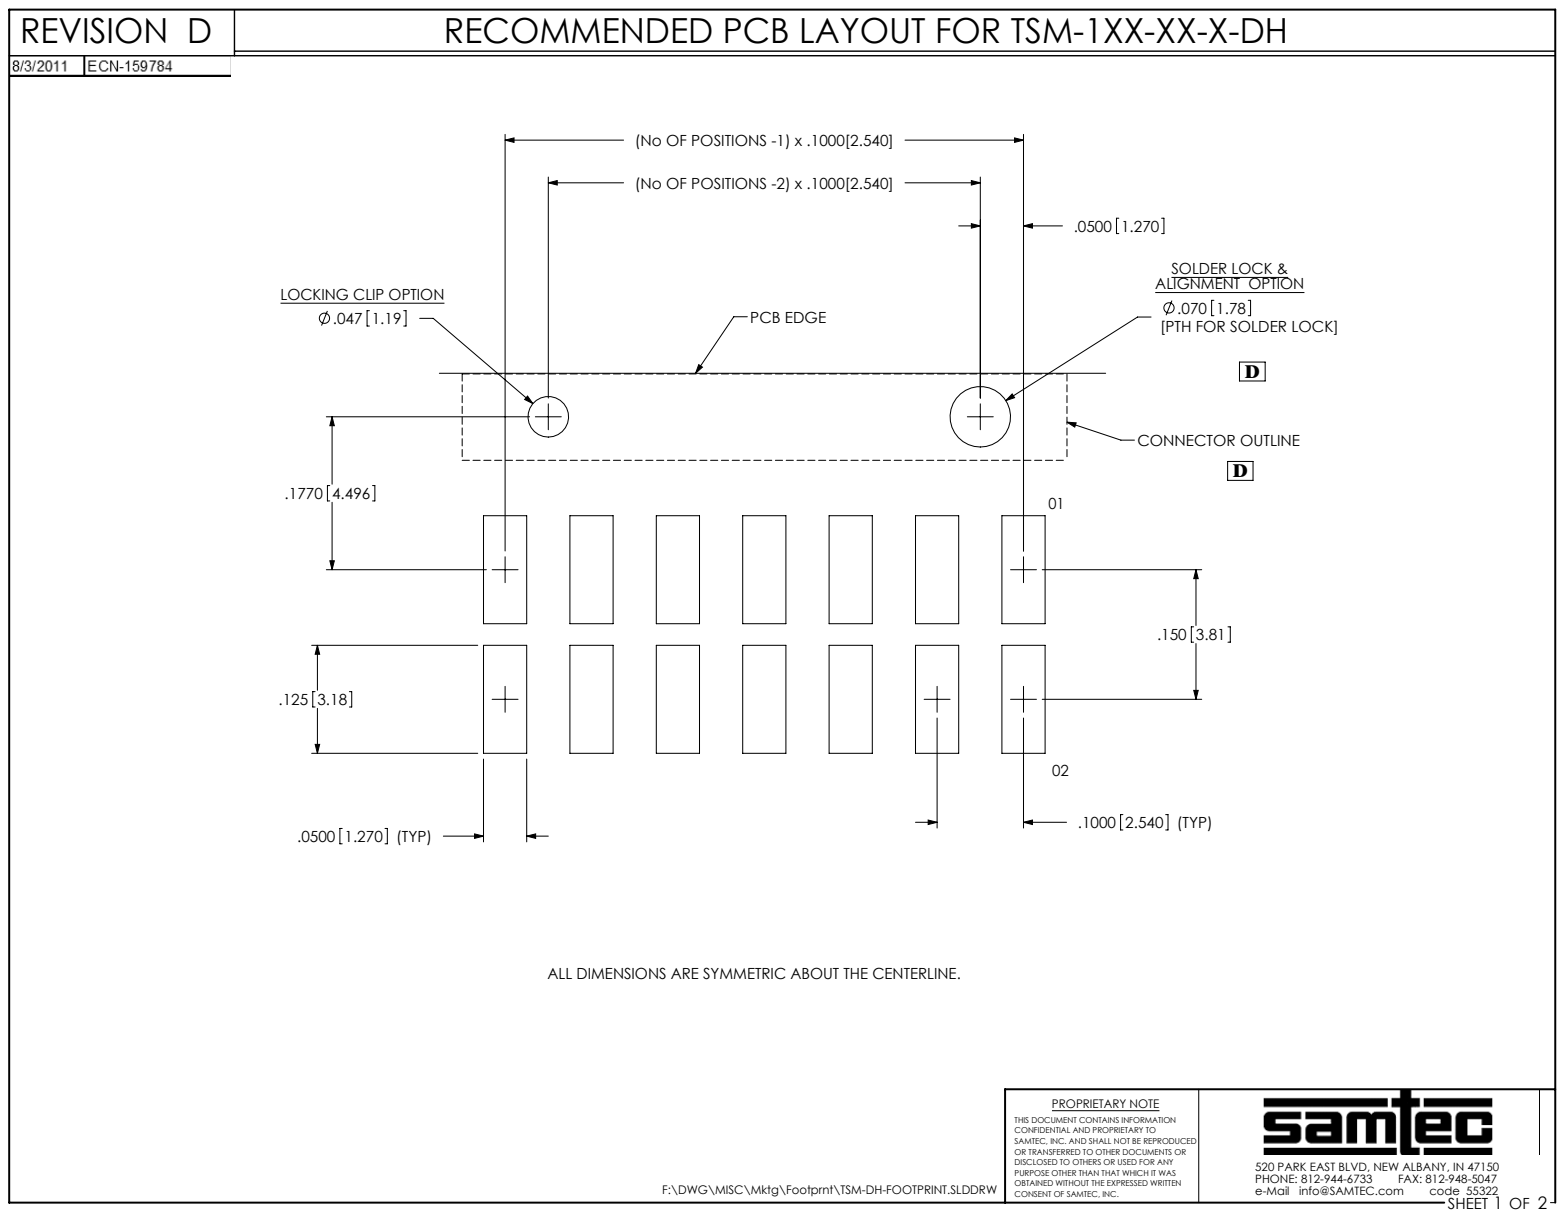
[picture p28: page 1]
.1000 2.540 (TYP) .0500 1.270 (TYP); SOLDER LOCK & ALIGNMENT OPTION; CONNECTOR OUTLINE; PCB EDGE; SHEET OF; PROPRIETARY NOTE; CONSENT OF SAMTEC, INC.; REVISION D; PHONE: 812-944-6733; FAX: 812-948-5047; e-Mail info@SAMTEC.com; code 55322

RECOMMENDED PCB LAYOUT FOR TSM-1XX-XX-X-DH

(No OF POSITIONS -1) x .1000[2.540]

(No OF POSITIONS -2) x .1000[2.540]

LOCKING CLIP OPTION

[PTH FOR SOLDER LOCK]

ALL DIMENSIONS ARE SYMMETRIC ABOUT THE CENTERLINE.

THIS DOCUMENT CONTAINS INFORMATION
CONFIDENTIAL AND PROPRIETARY TO
SAMTEC, INC. AND SHALL NOT BE REPRODUCED
OR TRANSFERRED TO OTHER DOCUMENTS OR
DISCLOSED TO OTHERS OR USED FOR ANY
PURPOSE OTHER THAN THAT WHICH IT WAS
OBTAINED WITHOUT THE EXPRESSED WRITTEN

520 PARK EAST BLVD, NEW ALBANY, IN 47150

F:\DWG\MISC\Mktg\Footprnt\TSM-DH-FOOTPRINT.SLDDRW

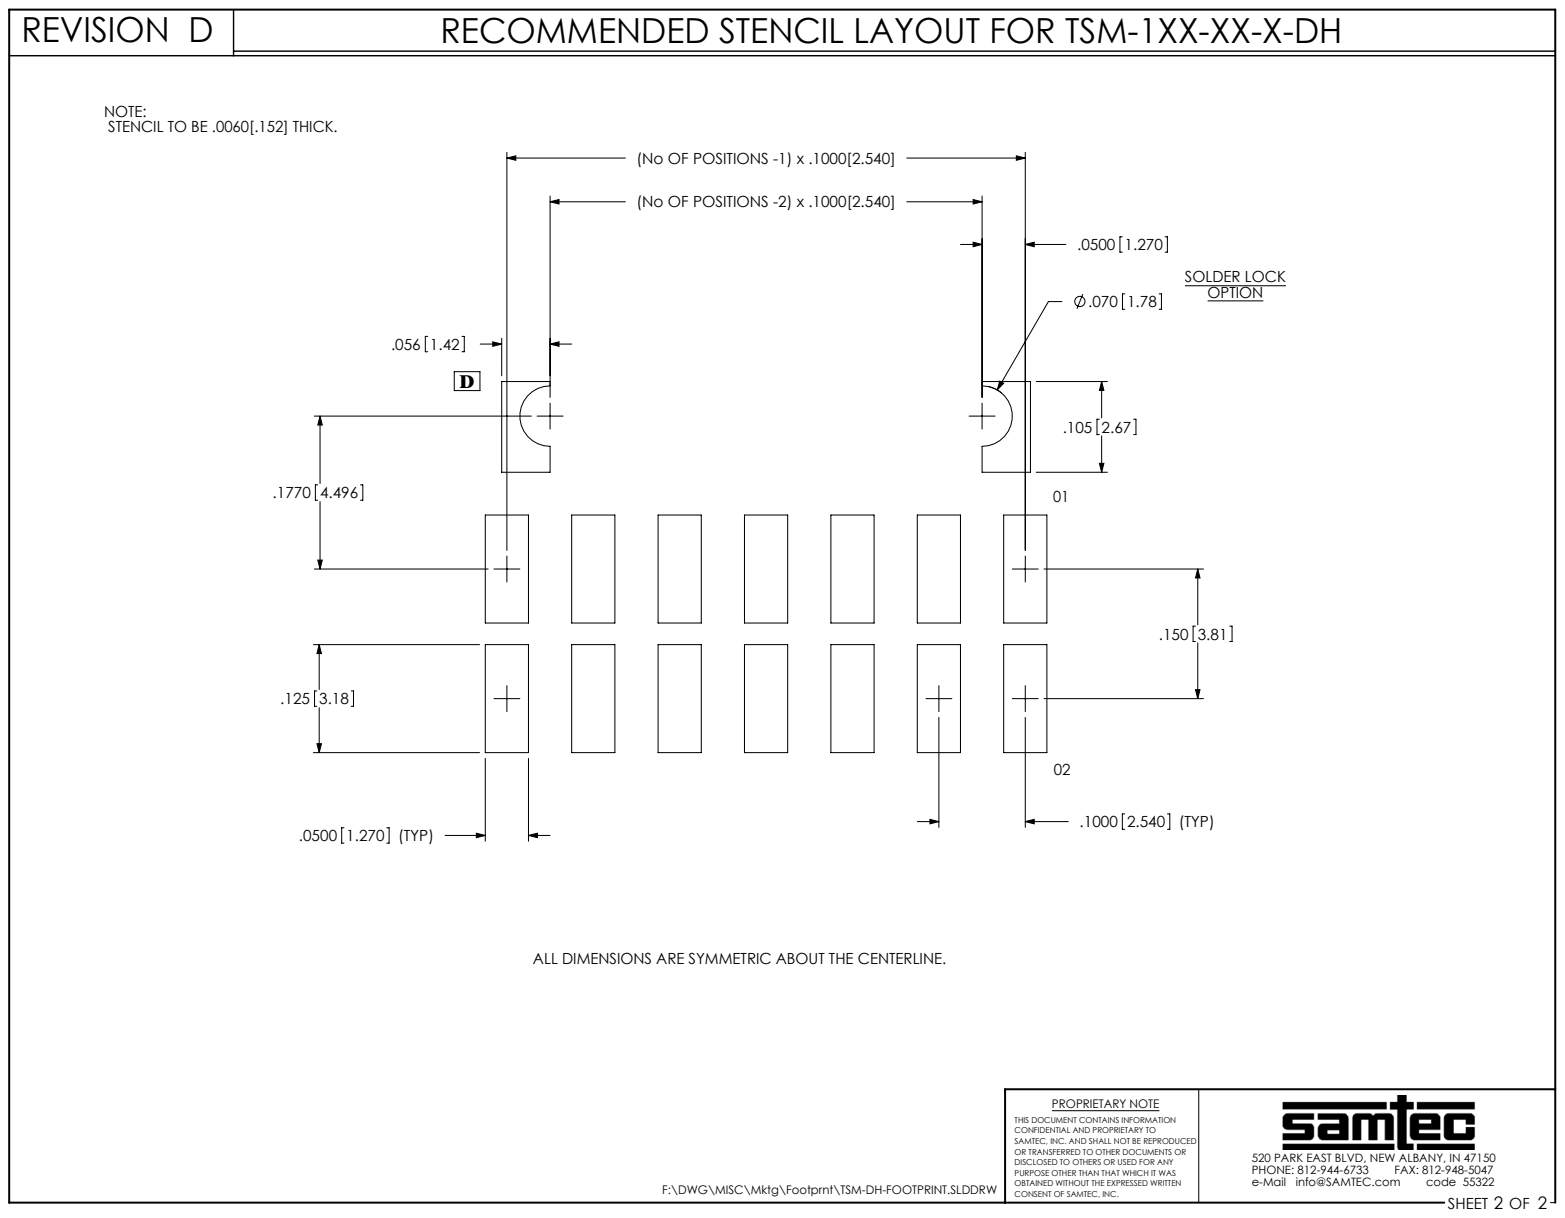
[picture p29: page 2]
.1000 2.540 (TYP) .0500 1.270 (TYP); SOLDER LOCK; SHEET OF; PROPRIETARY NOTE; CONSENT OF SAMTEC, INC.; REVISION D; PHONE: 812-944-6733; FAX: 812-948-5047; e-Mail info@SAMTEC.com; code 55322

RECOMMENDED STENCIL LAYOUT FOR TSM-1XX-XX-X-DH

NOTE:
STENCIL TO BE .0060[.152] THICK.

(No OF POSITIONS -1) x .1000[2.540]

(No OF POSITIONS -2) x .1000[2.540]

ALL DIMENSIONS ARE SYMMETRIC ABOUT THE CENTERLINE.

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

520 PARK EAST BLVD, NEW ALBANY, IN 47150

F:\DWG\MISC\Mktg\Footprnt\TSM-DH-FOOTPRINT.SLDDRW

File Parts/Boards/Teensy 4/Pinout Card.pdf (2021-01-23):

# Welcome to Teensy 4.1

To begin using Teensy, please visit the website & click Getting Started.

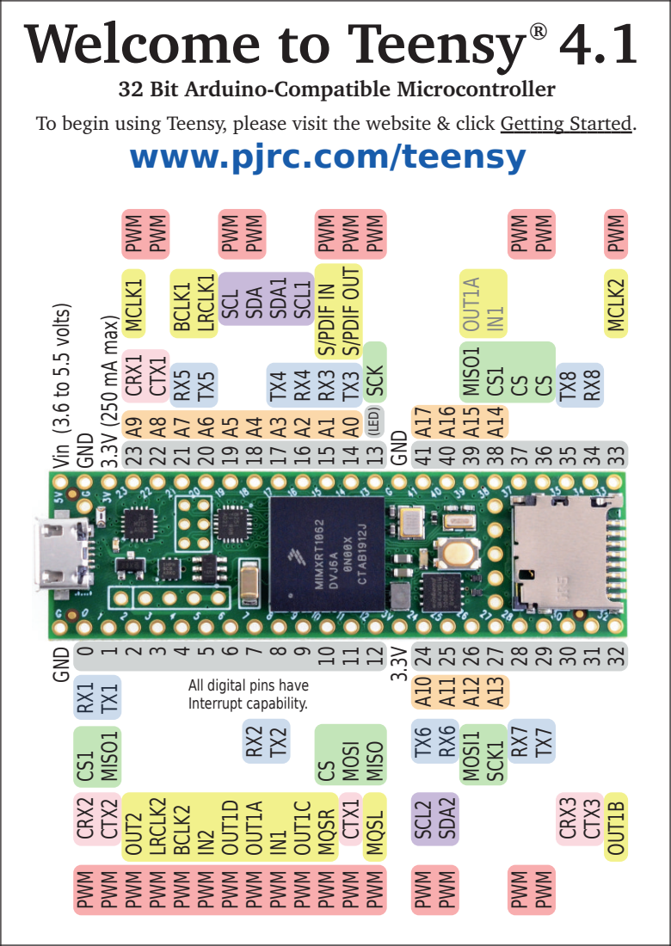
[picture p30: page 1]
GND 0; GND; (LED); max); CRX1 CTX1; SCK; MISO1; OSI; MISO; OSI1 SCK1; OUT2; LRCLK2 BCLK2; OUT1D OUT1A; OUT1C; QSR; QSL; OUT1B; MCLK1; BCLK1; LRCLK1; OUT1A; MCLK2; CRX2 CTX2; CTX1; SCL2; SDA2; CRX3 CTX3; SCL; SDA; SDA1 SCL1 S/PDIF IN; S/PDIF OUT

32 Bit Arduino-Compatible Microcontroller
www.pjrc.com/teensy

Vin (3.6 to 5.5 volts)

All digital pins have
Interrupt capability.

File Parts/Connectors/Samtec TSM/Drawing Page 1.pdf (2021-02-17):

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

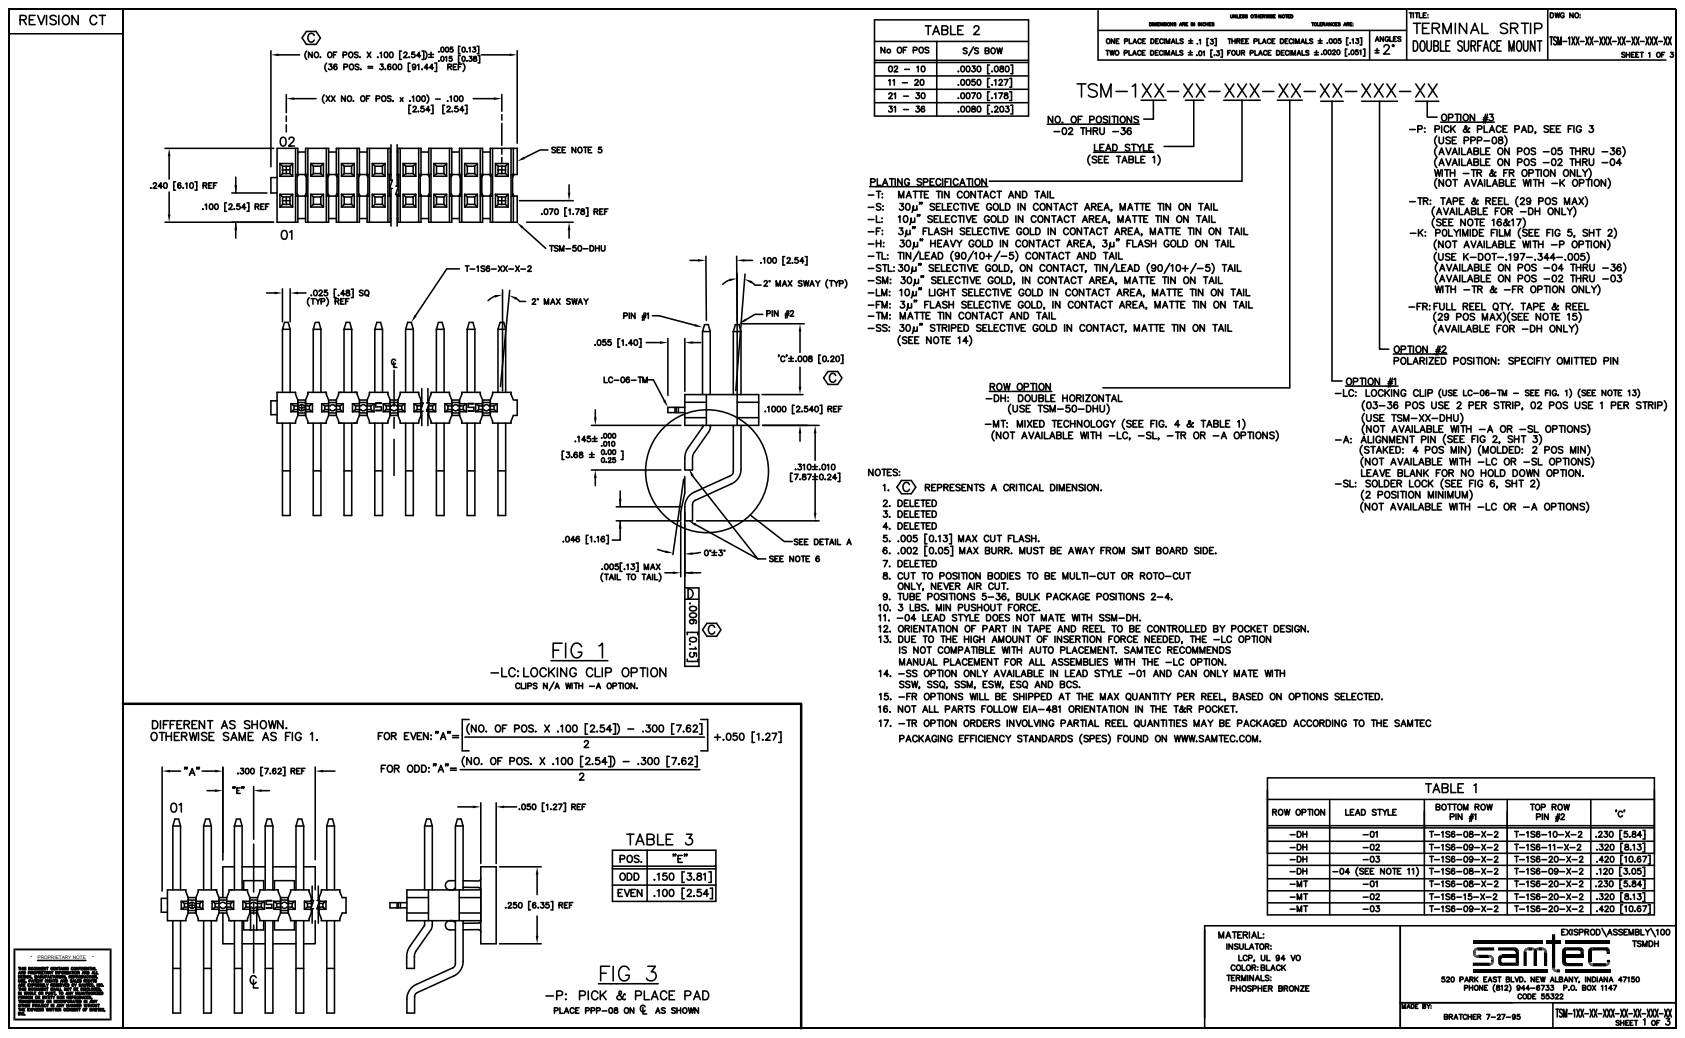
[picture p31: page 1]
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

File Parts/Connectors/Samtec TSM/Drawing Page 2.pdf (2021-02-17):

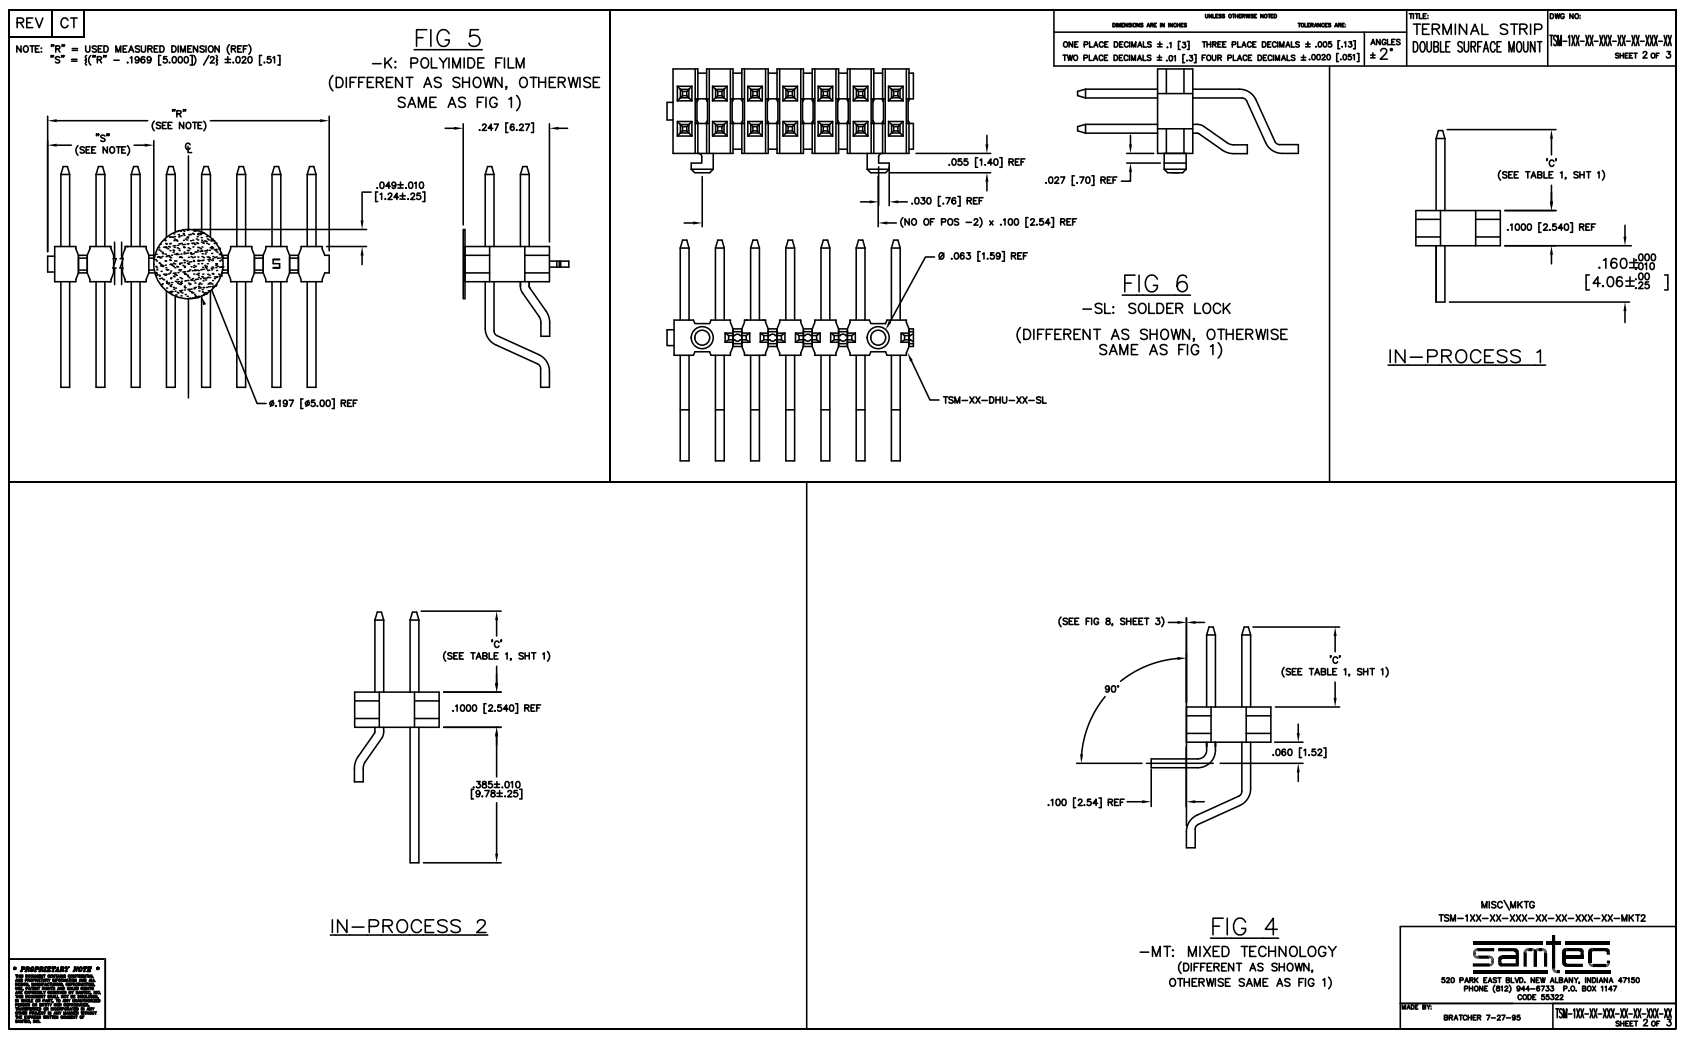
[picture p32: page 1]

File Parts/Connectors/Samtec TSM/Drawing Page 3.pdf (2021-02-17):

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

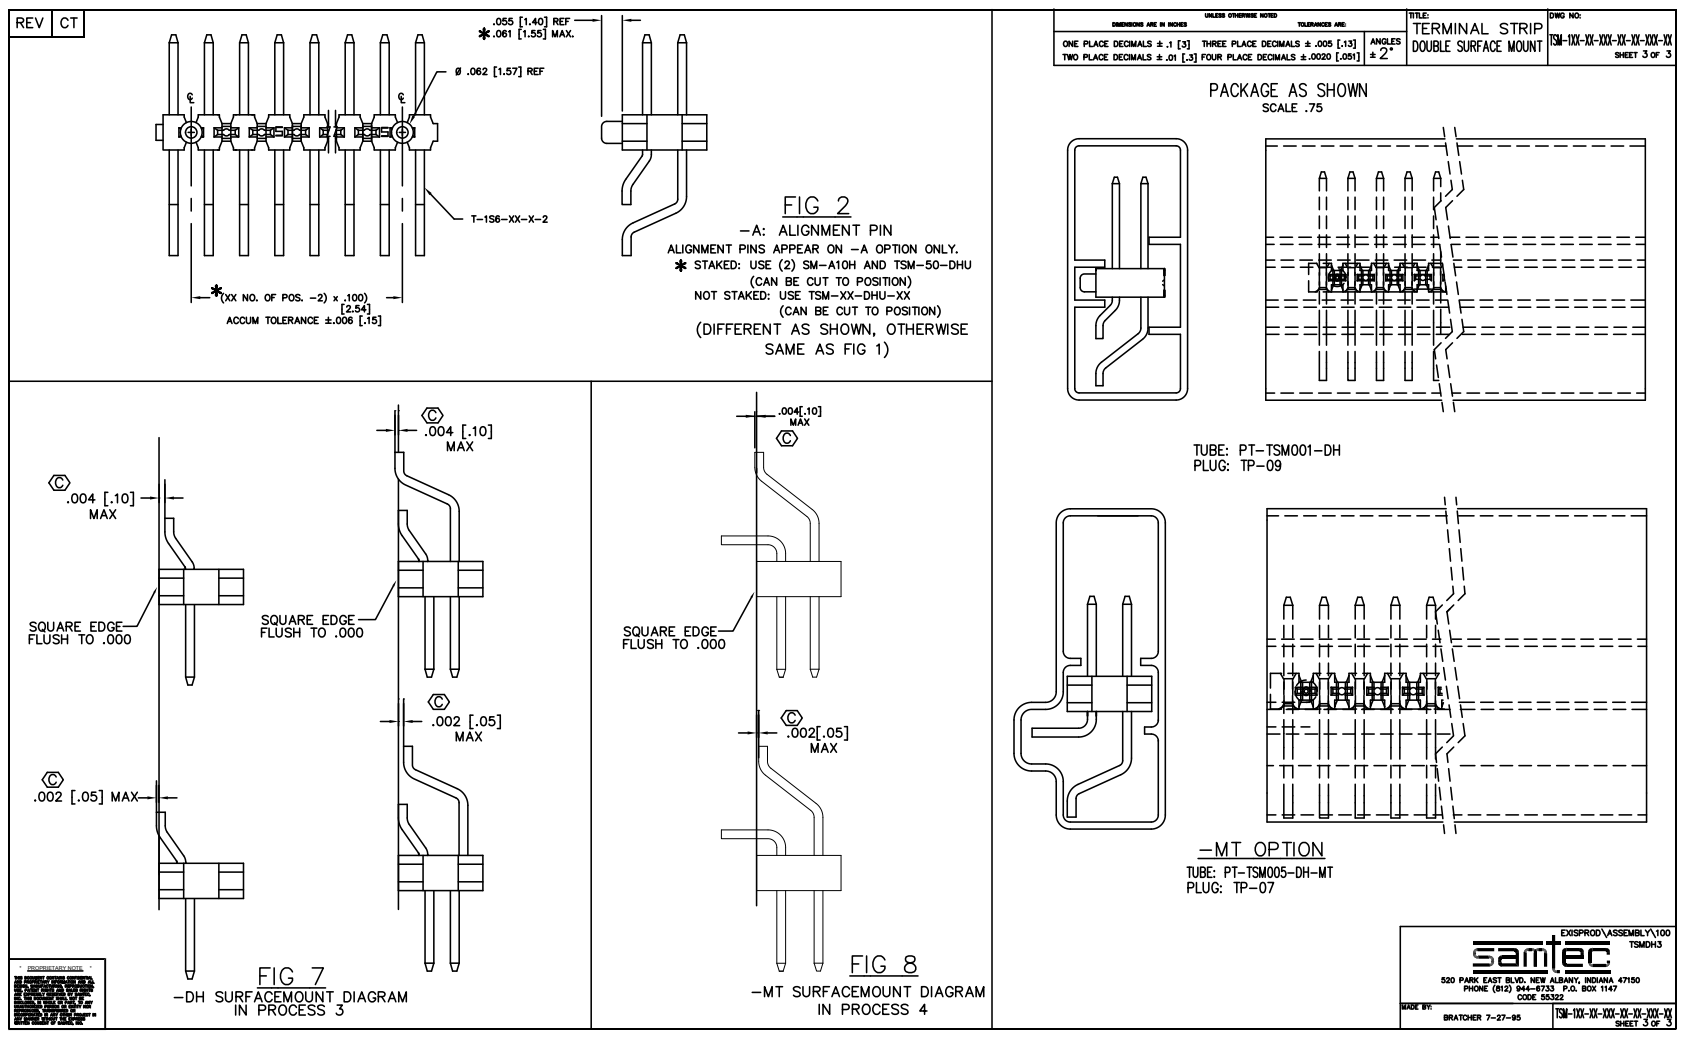
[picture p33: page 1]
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

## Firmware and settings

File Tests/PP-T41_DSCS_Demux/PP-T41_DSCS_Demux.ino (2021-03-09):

#include <SPI.h>

// Classes

struct SPIBusConfig {
  SPIClass &spi;
  const uint8_t sck_pin;
  const uint8_t copi_pin;
  const uint8_t cipo_pin;
};

class SPIBus {
  public:
    SPIBus(const SPIBusConfig &configuration) :
      configuration(configuration) {}

    const SPIBusConfig &configuration;

    void setup() {
      configuration.spi.setSCK(configuration.sck_pin);
      configuration.spi.setMOSI(configuration.copi_pin);
      configuration.spi.setMISO(configuration.cipo_pin);
      configuration.spi.begin();
    }
};

class MAX7317 {
  public:
    MAX7317(SPIBus &spi_bus, uint8_t cs_pin, unsigned long clock_freq = 26000000) :
      spi(spi_bus.configuration.spi), cs_pin(cs_pin), spi_settings(clock_freq, MSBFIRST, SPI_MODE0) {}

    static const uint8_t num_ports = 10;

    void setup() {
      pinMode(cs_pin, OUTPUT);
      digitalWrite(cs_pin, HIGH);
    }

    void setOutput(uint8_t port, bool level) {
      write(port, level);
    }

  private:
    SPIClass &spi;
    const uint8_t cs_pin;
    const SPISettings spi_settings;

    void write(uint8_t addr, uint8_t data) {
      spi.beginTransaction(spi_settings);
      digitalWrite(cs_pin, LOW);
      spi.transfer(addr);
      spi.transfer(data);
      digitalWrite(cs_pin, HIGH);
      spi.endTransaction();
    }
};

class BackboneSwitcher {
  public:
    static const uint8_t enable_port = 0;
    static const uint8_t addr_width = 4;

    BackboneSwitcher(MAX7317 &io_expander) :
      io_expander(io_expander) {}

    static constexpr uint8_t addr_port_mask(uint8_t port) {
      return 1 << port - 1;
    }

    void setup() {
      disable();
      set_addr(0);
    }

    void disable() {
      io_expander.setOutput(enable_port, HIGH);
    }
    void enable() {
      io_expander.setOutput(enable_port, LOW);
    }
    void set_addr(uint8_t addr) {
      for (uint8_t port = 1; port <= addr_width; ++port) {
        io_expander.setOutput(port, !(addr & addr_port_mask(port)));
      }
    }

  private:
    MAX7317 &io_expander;
};

// Backbone

static const uint8_t sck0_pin = 13;
static const uint8_t copi0_pin = 11;
static const uint8_t cipo0_pin = 12;
static const uint8_t mscs_pin = 30;
static const uint8_t dscs_pin = 31;
static const uint8_t num_addrs = 16;

// Application

static const SPIBusConfig spi0_config{SPI, sck0_pin, copi0_pin, cipo0_pin};
SPIBus spi0(spi0_config);
MAX7317 io_expander(spi0, mscs_pin);
BackboneSwitcher module_switcher(io_expander);
uint8_t addr = 0;

// Main

void setup() {
  Serial.begin(115200);

  // SPI devices should all be set up together to avoid crosstalk-induced activation on CS pins
  io_expander.setup();
  delay(1);

  // SPI bus setup should be done after setup of every SPI device
  spi0.setup();

  // Application
  module_switcher.setup();

  // Handshake
  unsigned long handshake_start = millis();
  while (true) {
    if (millis() - handshake_start > 1000) {
      Serial.println("Please ensure that the Serial Monitor is configured to use Newline as the line ending. Press enter to begin.");
      handshake_start = millis();
    }
    if (Serial.read() == '\n') {
      break;
    }
  }
  
  Serial.print("Generating ~1 kHz square wave on DSCS");
  Serial.print(addr);
  Serial.println("...");
  module_switcher.disable();
  module_switcher.set_addr(addr);
  module_switcher.enable();
}

void loop() {
  // Advance pin on \n
  while (Serial.available()) {
    if (Serial.read() == '\n') {
      addr = (addr + 1) % num_addrs;
      Serial.print("Generating ~1 kHz square wave on DSCS");
      Serial.print(addr);
      Serial.print(". Press enter to test DSCS");
      Serial.print((addr + 1) % num_addrs);
      Serial.println('.');
      module_switcher.disable();
      module_switcher.set_addr(addr);
      module_switcher.enable();
      break;
    }
  }

  // Toggle DSCS
  digitalWrite(dscs_pin, HIGH);
  delay(1);
  digitalWrite(dscs_pin, LOW);
  delay(1);
}

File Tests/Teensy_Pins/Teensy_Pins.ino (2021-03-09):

static const uint8_t num_pins = 42;
uint8_t pin = 0;

void setup() {
  for (uint8_t i = 0; i < num_pins; ++i) {
    pinMode(i, OUTPUT);
  }

  Serial.begin(115200);

  // Handshake
  unsigned long handshake_start = millis();
  while (true) {
    if (millis() - handshake_start > 1000) {
      Serial.println("Please ensure that the Serial Monitor is configured to use Newline as the line ending. Press enter to begin.");
      handshake_start = millis();
    }
    if (Serial.read() == '\n') {
      break;
    }
  }
  
  Serial.print("Generating ~1 kHz square wave on pin ");
  Serial.print(pin);
  Serial.println("...");
}

void loop() {
  // Advance pin on \n
  while (Serial.available()) {
    if (Serial.read() == '\n') {
      pin = (pin + 1) % num_pins;
      Serial.print("Generating ~1 kHz square wave on pin ");
      Serial.print(pin);
      Serial.print(". Press enter to test pin ");
      Serial.print((pin + 1) % num_pins);
      Serial.println('.');
      break;
    }
  }

  // Toggle pin
  digitalWrite(pin, HIGH);
  delay(1);
  digitalWrite(pin, LOW);
  delay(1);
}

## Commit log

2019-12-02 Added v0.1.0 board layout.
    [Control Board.brd, Control Board.sch]
2019-12-03 Made changes for v0.1.1
    Removed two MOSFET boards and two voltage step-up/step-down boards. Reassigned MOSFET control pins.
    Attempted to fix the 12V DC power barrel jack.
    Added jumper header block for controlling enable pins on motor driver boards.
    Tweaked positions of various components.
    Added 12V power supply switch and LED indicator.
    Added corner M3 mounting holes.
    Improved silkscreen and added missing labels.
    [Control Board.brd, Control Board.sch]
2019-12-03 Added board dimensions.
    [Control Board.brd]
2020-03-01 Made board for the v0.2.0 stack's initial (v0.1.0) processing plane.
    [BOM.csv, Control Board.brd, Control Board.sch]
2020-03-10 Made board for the stack's initial (v0.1.0) motion plane for Squid.
    [BOM - Components.csv, BOM - Fusion PCBA.csv, BOM - Manual Assembly.csv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]
2020-06-01 Made revised (v0.2.0) motion plane for Squid stack.
    Motor connectors are changed; UART addressing is used on the TMC2209 boards rather than an analog switch IC for multiplexing; and the DC power jack footprint is (hopefully) fixed.
    [BOM - Components.csv, BOM - Fusion PCBA.csv, BOM - Manual Assembly.csv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]
2020-06-01 Revised silkscreen labels for v0.1.1 processing plane for Squid stack.
    [BOM - Components.csv, BOM - Manual Assembly.csv]
2020-07-30 Change control panel connector for v0.2.0 processing plane
    [BOM - Components.csv, BOM - Fusion PCBA.csv, BOM - Manual Assembly.csv]
2020-12-01 Add pull-ups & change connectors for localization on motion plane
    [BOM - Components.csv, BOM - Fusion PCBA.csv, BOM - Manual Assembly.csv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]
2020-12-21 Add HMI board for Squid and Gravity Machine
    * easyEDA and Altium for HMI
    * EasyEDA and Altium for HMI Layout and Schematic
    * Rename files and folders
    * Add image preview, PDFs, BOM, and assembly files for HMI board
    [BOM - Components.csv, BOM - Fusion PCBA.csv, BOM - Manual Assembly.csv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]
2021-01-23 Prototype backbone template and processing plane for v1.0.0 stack (#4)
    * Remove files for ODMv0.1.0 and ODSv0.2.0
    * Add manufacturer assets for FX20 connectors
    * Add symbols and footprints for FX20 connectors
    * Start schematic for backplane template
    * Associate backplane template symbols with footprints and BOM info
    * Remap pins for easier layout
    * Start layout for backplane template
    * Add silkscreen documentation text
    * Resolve DRC problems
    * Add missing traces for backplane connector
    * Fix pin types in connectors
    * Change GPIO pins to bidirectional
    * Improve plane documentation silkscreen label
    * Add dimensions in fab layer and add layout page field v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
    [172316-1108.FCStd, 172316-1108.step, 172316-1108.stp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]
2021-01-23 Enable manual triggering of KiCad export workflow (#8)
    * Handle case of invalid SHA for previous commit
    * Allow manually specifying commit & boards to export
    * Add error message for nonexistent boards
2021-01-30 Enable generation of BOM variants from manually-triggered KiCad export workflow (#9)
    * Implement BOM variants, fix board silk positions for J1 and J2 refs
    * Include variant file ID in filenames
    * Fix variant selection
    * Remove variant file id from files which don't depend on variant
    * Add documentation related to variants
    * Trigger export workflow on modification of the variants config file
    * Fix duplicate board exporting
    * Fix typo in readme and bump date for PP-T41
    [Backbone.sch, Connectors.sch, HMIBoard.sch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]
2021-02-17 Prototype breakout plane (#11)
    * Remove superfluous Fab labels from Hirose FX20 footprints
    * Add files and models for 1x16 and 2x10 horizontal SMT male headers.
    * Move Preview Renders directories up a level
    * Update footprints on BT and PP-T41 for KiCad 5.1.9
    * Fix capacitor arrangement for the DCS selector in BT
    * Fix positioning of 3D model for TSM-110-01-x-DH
    * Add edge horizontal headers for BP-Jmp
    * Fix hierarchical pin label directions, finish front right corner
    * Finish routing GPIO and UART headers
    * Finish rear right corner
    * Finish routing I2C headers
    * Make traces between ICs and decoupling caps thicker in BT and PP-T41
    * Fix incorrect thermal s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
    [24342.FCStd, 24342.step, 504050-0691.FCStd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]
2021-03-09 Add basic unit tests for PP-T41 (#19)
    * Add datasheets for LEDs
    * Add test sketch to cycle through each Teensy pin and make a square wave
    * Add sketch to flash indicator LEDs on PP-T41 individually in a cycle
    * Refactor Status_Indicators test
    * Remove datasheets for Lite-On LEDs because they will be replaced for #14
    * Add README documentation for running the tests
    * Add README for PP-T41 status indicator LEDs cyclical blinking test
    * Fix typoes in READMEs for unit tests
    * Fix error in ODSv1.0.0-BP-Jmp/README.md's pin assignments table
    * Add PP-T41 DSCS demultiplexing test
    [PP-T41_DSCS_Demux.ino, PP-T41_Status_Indicators.ino, Teensy_Pins.ino]
2021-03-09 Make minor improvements to PP-T41 (#20)
    * Fix 3D models for Teensy 4.1 and female headers to mount it (#18)
    * Add header as test points for signal not exposed on the backbone (#15)
    [Backbone.sch, Connectors.sch, HMIBoard.sch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]
2021-03-10 Reduce brightnesses of indicator LEDs (#21)
    * Change indicator LEDs and make them dimmer (#14)
    * Bump patch version number of BP-Jmp
    * Add README with license information for WL-SMCW LED datasheets
    [Backbone.sch, Communication Breakout.sch, Connectors.sch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]
2021-03-19 Fix implementation of SPI CS multiplexing system (#22)
    * Disconnect PP-T41's MAX7317's DOUT, since it's not needed anyways (#16)
    * Disconnect BT & BP-Jmp backbone MAX7317 DOUT (#16); make DOUT output pin
    * Replace DAC with a second MAX7317 expander with pullup resistors
    * Insert 3-state buffers between MAX7317 DOUTs and CIPO in BP-Jmp (#16)
    * Update symbol fields for I/O expansion components in BP-Jmp
    * Consolidate free space by moving the AD7689 chip
    * Add pull-ups on demuxed DCS (#17), move pull-ups to bottom of BP-Jmp
    * Insert 3-state buffers between all MAX7317 DOUTs and CIPO (#16)
    * Add bypass caps to the 3-state buffers for BP-Jmp's I/O expanders
    * Fix title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
    [Backbone.sch, Communication Breakout.sch, Connectors.sch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]
